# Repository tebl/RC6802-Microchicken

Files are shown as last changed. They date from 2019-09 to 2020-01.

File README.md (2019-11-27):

# RC6802 Microchicken

When starting out with retro computers, both fictional made homebrew or the commercial ones that were actually available for purchase in the 70s and 80s, there's one book in particular I've particularly enjoyed reading - that book is "22 micro-computer projects - to build, learn and learn" by Daniel Metzger (check out [ebay](http://ebay.com) or [abebooks.com](http://abebooks.com) for a copy). Written in 1985 on the tail-end of the homebrew computer-period, it gathers what I believe is the culmination of 10 years of teaching basic electronics, digital logic and computers to people without any prior knowledge for any of those things - perfect for me!

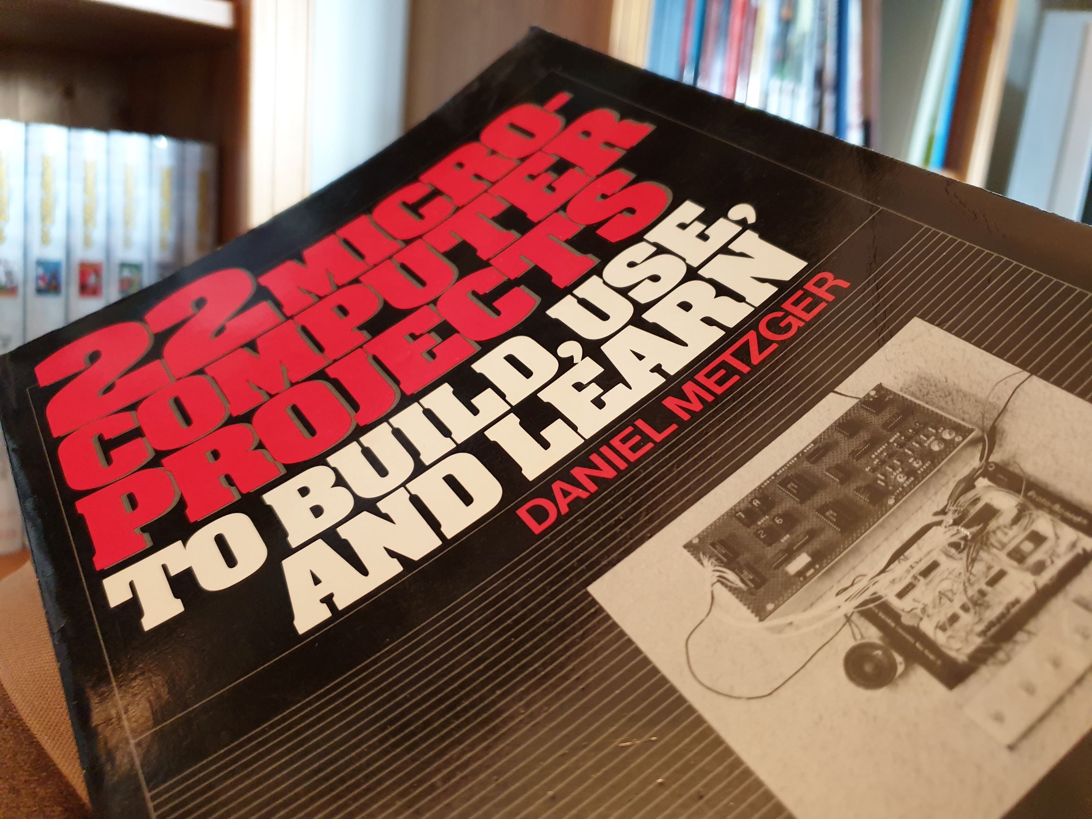
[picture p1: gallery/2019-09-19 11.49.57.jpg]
22 micro-computer projects - to build, learn and learn


The book builds upon each chapter by building a computer based on the 6802-processor from Motorola, a mysteriously similar processor to the now far more popular 6502. While it might be seen as an odd choice for a main processor these days, even the most advanced circuits are easily adapted to the 6502 as well. Nearly every other book I've got in my bookshelf never seem to describe much past the basics, usually circuits for storage (tape-based), single-step circuits as well as using a Video Display Generator are details left for other books to fill - this is the only book I've got that actually shows how to implement them in an easy and understandable way.

The final projects in the book result in the Microchicken-computer, which I've adapted and laid out in the form of the RC6802 Microchicken computer. I have no idea why it's called the *Microchicken*, other than that the book author obviously had a peculiar sense of humour that I can't help but agree with. My current build of the computer is shown below, I also made a short [YouTube](https://www.youtube.com/watch?v=bi4SIbvGzfI)-clip where I push some of its buttons - a whole bunch of times!

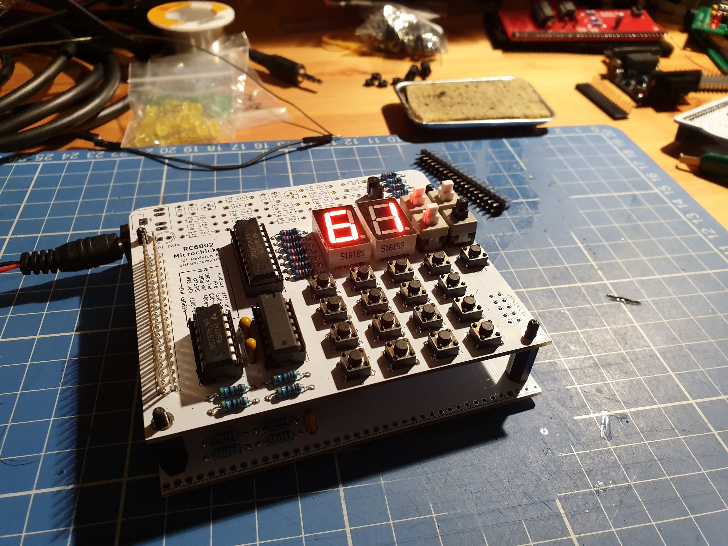
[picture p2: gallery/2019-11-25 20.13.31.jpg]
RC6802 Microchicken Computer


The monitor software for the RC6802 Microchicken, like the hardware design itself, is also included in the aforementioned book. I've transcribed in and slightly adapted the assembly code so that it can be assembled using modern tools, the one I've chosen to use is [SB-Assembler 3](https://www.sbprojects.net/sbasm/) as it seems to support all of the 8bit CPUs I've managed to force upon it. For a further description on the various functions of the monitor and the firmware in , see its specific [README](https://github.com/tebl/RC6802-Microchicken/tree/master/software/firmware)-file as well. 

## Modules
As with most of my computer builds the computer have been split into two required main boards to stay under the magic 5$ cost limits over at [PCBWay](https://www.pcbway.com/setinvite.aspx?inviteid=88707) for each, a CPU board as well as a UI board sandwiched on top. There may be additional modules found among the project files, but the ones I've added here are the ones that have been considered ready.

| Module | RC6802 Microchicken | Expanded system | Order |
| --- | --- | --- | ----- |
| [CPU](https://github.com/tebl/RC6802-Microchicken/tree/master/RC6802%20CPU) | required | required | [PCBWay](https://www.pcbway.com/project/shareproject/RC6802_Microchicken__CPU_module_revision_B_.html?inviteid=88707) |
| [User Interface](https://github.com/tebl/RC6802-Microchicken/tree/master/RC6802%20UI) | required | required | [PCBWay](https://www.pcbway.com/project/shareproject/RC6802_Microchicken__UI_module_revision_B_.html?inviteid=88707) |
| [Backplane](https://github.com/tebl/RC6502-Apple-1-Replica/tree/master/RC6502%20Backplane) | | required | [PCBWay](https://www.pcbway.com/project/shareproject/RC6502_Apple_1_Replica__Backplane_module_revision_A_.html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) |
| [Prototyping module](https://github.com/tebl/RC6502-Apple-1-Replica/tree/master/RC6502%20Prototyping) | | optional | [PCBWay](https://www.pcbway.com/project/shareproject/RC6502_Apple_1_Replica__Module_prototyping_board_.html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) |

As modules are constantly being worked on, I've also added an order link to the modules so that you can always get the last version I know works. Click the module name for more information about that specific module, including schematic and the list of parts you'd need to build it (BOM).

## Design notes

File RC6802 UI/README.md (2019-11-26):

# RC6802 Microchicken

One of my most enjoyable reads the past year has been "22 micro-computer projects - to build, learn and learn" by Daniel L. Metzger, the Microchicken-computer is described in detail within it and so I sought to build one myself. The computer has been designed as a set of smaller modules, for an overall description a listing of the available modules - see the main project [README](https://github.com/tebl/RC6802-Microchicken)!

## User Interface
The User Interface module has been designed to stack on top of the CPU-module, doing it this way the overall project stays within manageable PCB-costs and should be buildable for anyone with a reasonable set of tools available. An assembled version of the CPU-module by itself as well as a version stacked underneath the User Interface module can be seen below.

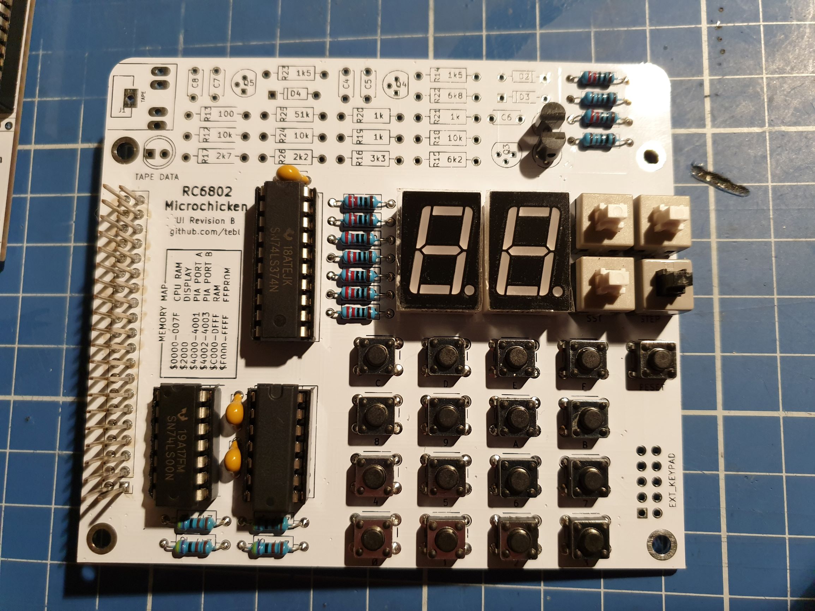
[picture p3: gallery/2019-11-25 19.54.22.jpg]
Assembled User Interface

Stacked boards

The User Interface has two 7-segment displays as well as a 16-key keypad, all of the keypad pins have also been brought out to a separate connector so that an external keypad can also be used instead of the onboard-one (easier when using the computer with a backplane and additional expansions). It has an implementation of the described SST-circuit for the 6802 processor as well as being able to latch the IRQ-line permanently low, this is used by the monitor as a software-based alternative for stepping through code.

Additionally a circuit for loading and saving data using audio tapes is also available as an option, I only had room to add the one audio connector so I used a single 3.5mm connector instead. I used the same pinouts as on the ZX Spectrum +3, so the same tape cables can be used with the RC6802 and you should be able to find a new set of these cables via ebay as they are still being made today.

# Schematic
The supplied KiCad files should be sufficient as both a schematic and as a starting point for ordering PCBs (basically you could just zip the contents of the export folder and upload that on a fabrication site), the schematic is also available in [PDF-format](https://github.com/tebl/RC6802-Microchicken/raw/master/RC6802%20UI/export/RC6802%20UI.pdf) so that you print it out and hang it on your office wall, excellent conversation starter at any technology-oriented business worth working at (or so I keep telling myself)!

If you require more assistance, there is also a separate [Troubleshooting](https://github.com/tebl/RC6802-Microchicken/blob/master/Troubleshooting.md) guide as part of the supplied documentation. Also make sure to have a read through the [Manual](https://github.com/tebl/RC6802-Microchicken/blob/master/Manual.md) to see if it's a *feature* instead! Some of these documents may not actually exist at the time of clicking on them.

# BOM
This is the part list as it stands now, most should be easy to get a hold of from your local electronic component shop though you might have to consider other sources depending on the quality of your local vendor. Values in parenthesis are optional components that might not be needed (mainly the tape interface and the SST-circuit).

Some vendors will have the same ICs in different form factors, the ones you want will often be specified as being in the form of a DIP/PDIP package - usually you'll want sockets for each of them as well. For the pin headers, you probably won't find the exact pin count so just buy the 40 pin versions and snip off the parts you don't need.

| Reference | Item | Count |
| --- | --- | ----- |
| PCB | Fabricate yourself using Gerber files | 1 |
| AFF1-AFF2 | 0.56" 7-segment displays (C.A.) | 2 |
| C1-C3 | 100nF ceramic capacitor | 3 |
| C4,C6 | 50nF ceramic capacitor | (2)|
| C5 | 68nF ceramic capacitor | (1)|
| C8 | 100nF ceramic capacitor | (1)|
| D1 | 5mm LED | (1)|
| D2-D4 | 1N4148 small signal diode | (3)|
| J1 Audio | 3.5mm 5pin green audio socket (PJ307) | (1)|
| J2 | 2x20 female header pins * | 1 |
| J3 | 2x5 right-angle header pins | (1)|
| Q1-Q2 | 2N3906 TO-92 transistor | 2 |
| Q3-Q5 | 2N3904 TO-92 transistor | (3)|
| R13 | 100 ohm resistor | (1)|
| R27,R29 | 220 ohm resistor | 2 |
| R28,R30 | 1k (1000) ohm resistor | 2 |
| R19-R21 | 1k ohm resistor | (3)|
| R14,R23 | 1k5 (1500) ohm resistor | (2)|
| R1-R4 | 4k7 (4700) ohm resistor | 4 |
| R26 | 2k2 (2200) ohm resistor | (1)|
| R17 | 2k7 (2700) ohm resistor | (1)|
| R22 | 6k8 (6800) ohm resistor | (1)|
| R12,R18,R24 | 10k ohm resistor | (3)|
| R25 | 51k ohm resistor | (1)|
| SW1,SW3-SW18 | Momentary push button | 17 |
| SW2,SW19,SW21 | 6pin 8.5mm x 8.5mm latching switch | (3)|
| SW20 | 6pin 8.5mm x 8.5mm non-latching switch| (1)|
| U1 | 74LS374 (DIP-20) | 1 |
| U2 | 74LS00 (DIP-14) | 1 |
| U3 | 74LS73 (DIP-14) | (1)|
| | M3 nylon hex standoffs ** | 4 |
| | M3 nylon screws ** | 4 |
| | M3 nylon nuts ** | 4 |

*) An ordinary set of 2x20 female header pins can be installed on the reverse-side, but since the connector has quite a few signals that could be used for your own projects later I recommend getting ones with the longer pins - these are most oftenly found listed as a stacking Raspberry Pi header. Slot onto CPU-module using M3 standoffs before soldering to get the spacing correct.

**) The length of the nylon standoffs depend on the female header pins used, extra length (M3x12mm) or the ordinary non-stacking variant (M3x10mm). Better yet, get one of those $4 M3 Nylon Stand-off sets from China - that way you're all set for a few projects down the road as well.

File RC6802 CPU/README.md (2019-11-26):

# RC6802 Microchicken

One of my most enjoyable reads the past year has been "22 micro-computer projects - to build, learn and learn" by Daniel L. Metzger, the Microchicken-computer is described in detail within it and so I sought to build one myself. The computer has been designed as a set of smaller modules, for an overall description a listing of the available modules - see the main project [README](https://github.com/tebl/RC6802-Microchicken)!

## CPU
The CPU module has been designed to stack with the User Interface-module, doing it this way the overall project stays within manageable PCB-costs and should be buildable for anyone with a reasonable set of tools available. An assembled version of the CPU-module by itself as well as a version stacked underneath the User Interface module can be seen below.

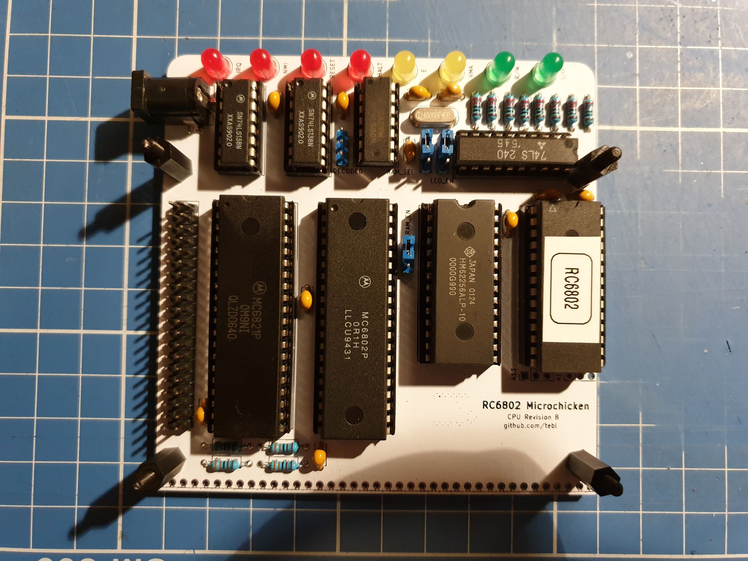
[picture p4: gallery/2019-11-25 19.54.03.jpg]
Assembled CPU Board

Stacked boards

The CPU board is actually a complete SBC (Single Board Computer) by itself, meaning that it can be used either standalone though you'd probably need to add some sort of additional hardware in order to see anything actually running. I hope to build more modules that can be used with it other than the standard User Interface. 

Some of the ICs however have been changed out with components that should be easier to source for a lot less money. For those that find themselves wondering why there are ICs with more capacity (RAM/ROM) than is actually available to the system, it's simply because they were cheaper than the smaller capacity variants and I didn't want to lay claim to more of the address space than what the original computer calls for (8K for each).

## Jumpers
| Reference | Position | Description |
| --- | --- | --- |
| RAM_EN | 1-2 * | Enable on-chip 128 bytes of memory on 6802 CPU |
| | 2-3 | Disable on-chip memory or jumper if using 6808 CPU |
| RAM_SEL | 1-2 * | 8K of static RAM on addresses $C000-$DFFF |
| | 2-3 | 8k of static RAM on addresses $0000-$1FFF |
| LED_EN | 1-2 * | Enable status LEDs |
| | 2-3 | Disable status LEDs |
| A14, A13  | 1-2 ** | EEPROM 8K window selection (sets line HIGH) |
| | 2-3 ** | EEPROM 8K window selection (sets line LOW) |

*) Marks the default jumpered positions for a standalone RC6802 system with 6802 CPU installed.
**) A14 and A13 must be jumpered when using 28C256 EEPROM, leave unjumpered when using the lower capacity 28C64 EEPROM instead.

# Schematic
The supplied KiCad files should be sufficient as both a schematic and as a starting point for ordering PCBs (basically you could just zip the contents of the export folder and upload that on a fabrication site), the schematic is also available in [PDF-format](https://github.com/tebl/RC6802-Microchicken/raw/master/RC6802%20CPU/export/RC6802%20CPU.pdf) so that you print it out and hang it on your office wall, excellent conversation starter at any technology-oriented business worth working at (or so I keep telling myself)!

If you require more assistance, there is also a separate [Troubleshooting](https://github.com/tebl/RC6802-Microchicken/blob/master/Troubleshooting.md) guide as part of the supplied documentation. Also make sure to have a read through the [Manual](https://github.com/tebl/RC6802-Microchicken/blob/master/Manual.md) to see if it's a *feature* instead! Some of these documents may not actually exist at the time of clicking on them.

# BOM
This is the part list as it stands now, most should be easy to get a hold of from your local electronic component shop though you might have to consider other sources depending on the quality of your local vendor. Values in parenthesis are optional components that might not be needed (status LEDs and when using 28C256 EEPROMs).

Some vendors will have the same ICs in different form factors, the ones you want will often be specified as being in the form of a DIP/PDIP package - usually you'll want sockets for each of them as well. For the pin headers, you probably won't find the exact pin count so just buy the 40 pin versions and snip off the parts you don't need.

| Reference | Item | Count |
| --- | --- | ----- |
| PCB | Fabricate yourself using Gerber files | 1 |
| C1-C8,C10 | 100nF ceramic capacitor | 9 |
| C9,C11 | 22pF ceramic capacitor | 2 |
| D1-D8 | 5mm LED (assorted colours) | (8)|
| J1 | 39p right angle pin header | (1)|
| J2 | 2x20 pin straight header | 1 |
| J3 | 2.1mm x 5.5mm barrel plug | 1 |
| J4,JP7-JP8 | Single row, 3 pin straight  header | (3)|
| JP2,JP3 | Single row, 3 pin straight  header | 2 |
| R1-R4 | 3k3 (3300) ohm resistor | 4 |
| R5-R12 | 220 ohm resistor | (8)|
| U1 | MC6802 CPU (DIP-40) * | 1 |
| U2 | 62256 Static RAM (DIP-28) | 1 |
| U3 | 28C64/28C256 EEPROM (DIP-28) | 1 |
| U4 | 74LS00 (DIP-14) | 1 |
| U6 | MC6821 PIA (DIP-40) | 1 |
| U7 | 74LS138 (DIP-16) | 1 |
| U8 | 74LS240 (DIP-20) | (1)|
| Y1 | 4Mhz crystal (HC-49) | 1 |
| | Jumpers for settings (CAP headers) | 5 |

*) You can also use an MC6808 processor, read jumpers descriptions on how to do this. The 6808 lacks the on-chip memory found on the 6802, so it needs to be jumpered as disabled with static memory moved into the lower addresses instead.

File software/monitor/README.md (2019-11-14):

# Firmware
The monitor software for the RC6802 Microchicken, like the hardware design itself - it is taken from the book "22 Micro-computer projects: To build, use, and learn" by the late Daniel Metzger. The assembly code listed in the book has been transcribed by me, then adapted slightly so that the code assembles as expected when using [SB-Assembler 3](https://www.sbprojects.net/sbasm/).

SB-Assembler 3 is available for all major platforms, so apart from my simple little batch file to run it there shouldn't be any other steps necessary other than adding it to the system PATH environment variable. If you do not wish to alter the code, then the Intel HEX file should be suitable for flashing onto a 28C64 EEPROM - an additional file, monitor.list makes reading the code easier when debugging the software. The batch file is just there because I'm too lazy to type the command, so I'll just click it instead. Essentially what it does is this:
```
sbasm.py monitor.asm
```

## MICROCHICKEN 6802 MONITOR
Microchicken 6802 Monitor is copyright 1984 by the late Daniel L. Metzger, and as already mentioned I've reproduced the listing from his book in the hope that it again ends up teaching someone, something, someday.

The Microchicken monitor is a simple operating system for the 6802 microcomputer, it permits commands and data to be input to the computer via the hex keyboard (either directly on the UI module or via an external keypad). Data is displayed on two 7-segment displays found on the UI-module, the monitor contains a lookup table used when translating from binary hex digits into the corresponding display segments.

Pressing the *RESET*-button causes the program to start scanning the keyboard for the function (*FCN*) to be performed, any subsequent key entries access new functions according to the key pressed. Read the description for each function for a description of what to do from there, hit *RESET* again to exit out of the function.

**NB!** The *RESET* button is resetting the CPU, so just press and release *RESET* - then press a digit to enter the function as described below.

### (FCN-0) Set address
Enter address using keypad, 4 key inputs - address entered will be shown on the display. Both bytes, HI and LO will be flashed briefly on the displays followed by a blanking period when all digits of the address has been entered.

### (FCN-1) Display address
Displays data, 2 digits, of the currently set address on the first press. The address will automatically be incremented on subsequented presses of the *1*-key, allowing you to step through and verify a program you've keyed in before running it.

### (FCN-2) Set data
Displays data stored in currently set address on first press. New data (2 digits) is then entered via the hex keypad, the address is automatically incremented on subsequent pairs of keystrokes. Use *RESET* to stop entering data.

### (FCN-3) Display data
Displays data stored in currently set address on the first press. Subsequent presses of the *3* decrements the currently set address and displays the data stored there instead - this allows you to verify entered using FCN-2 in reverse order. Alternatively you could set the address to the start of your program using FCN-0 and then stepping through the data using FCN-1.

### (FCN-4) Run program
Executes the program starting at the currently set address.

### (FCN-5) Run from start
Computer will jump to address $0001, the then it will start executing instructions from there.

### (FCN-6) Burn EPROM
The book the that describes the Microchicken computer also include instructions for building a simple EPROM burner for 2716 EPROMs. This part of the hardware may be added in a future revision, or stripped out entirely because I wanted the function number for something else.

The function expects the RAM address of where the data to be written starts, this is as commonly expected stored with HI address $7A and LO at $7B. Data end address will likewise have to be put in addresses $7C/$7E. The address of where to start within the EPROM must be set up in addresses $7E/$7F. Takes 50ms per byte to run, displays ROM low address while programming followed by RAM end address when done - displays bad EPROM adress if data verification fails.

### (FCN-7) Dump EPROM
Dump contents of EPROM connected to the EPROM-burner part of the Microchicken, if you have this expansion for it (and you probably designed and built it yourself). See FCN-6 for more information.

RAM start address must be stored at $7A (HI)/$7B (LO), RAM end address at $7C/$7D. ROM start address at $7E/$7F.

### (FCN-8) Save RAM to TAPE
Saves RAM to tape using the tape interface included on the UI-module, this version of the hardware uses a single 3.5mm jack for both the EAR (data from tape to computer) and MIC (data from computer to tape) and uses the same cable used with the ZX Spectrum +3 as those are still being produced.

The tape interface will output one bit at a time, generating a 18 cycles with 3600Hz tone for a 0 or 9 cycles for a 1 done in an 8ms field. Note that this is dependent on the CPU speed and these values correspond to a default system clock running at around 1Mhz.   

Store starting address in RAM address $7A (HI) and $7B (LO), ending address at $7C/$7D. Takes 64ms per byte; 16 seconds per page. RAM end address will be displayed when done. Note that when loading data from tape, you'll need to know the length of the program in bytes as a the code does not write something akin to a program header to the tape.

### (FCN-9) Load data from TAPE
See FCN-8 for more details on the hardware-side of things. Store starting address in RAM address $7A (HI) and $7B (LO), ending address at $7C/$7D. The last address will be shown on the display when the program has read the specified number of bytes.

### (FCN-A) Display accumulator A
Displays the contents of accumulator A. Used after single-stepping code using the HW SST circuit.

### (FCN-B) Display accumulator B
Displays the contents of accumulator B. Used after single-stepping code using the HW SST circuit.

### (FCN-C) Display condition-code register
Displays the contents of the condition-code register, used after single-stepping code with the HW SST circuit. The register display bits are setup as following (see 6800 documentation for further details):

| bit | 7 | 6 | 5 | 4 | 3 | 2 | 1 | 0 |
| --- | - | - | --- | --- | --- | --- | --- | --- |
| | - | - | **H**alf-carry | **I**nterrupt mask | **N**egative | **Z**ero | o**V**erflow | **C**arry |

### (FCN-D) Display index register (X)
Displays the contents of the 16bit index register (X), used after single-stepping code with the HW SST circuit. HI and LO bytes will be flashed on displays, with a short pause before repeating.

### (FCN-E) Display program counter
Displays the contents of the 16bit program counter (PC), used after single-stepping code with the HW SST circuit this will show the address of the next instruction. HI and LO bytes will be flashed on displays, with a short pause before repeating.

### (FCN-F) Execute a single instruction
This function will execute a single instruction at the currently set address, performing the following steps:
1) Save the byte preceeding the user instruction, inserting a clear interrupt in its place.
2) Jumps to the "CLI" instruction. One user instruction will execute before IRQ is recognized, the IRQ handler will save all machine registers on stack and then go to *RETURN*.
3) Pull machine registers off stack, save contents in RAM buffers.
4) Replace inserted *CLI* instruction with the one overwritten in step 1.
5) Update program counter (PC) to point to the current address (ready for next step).

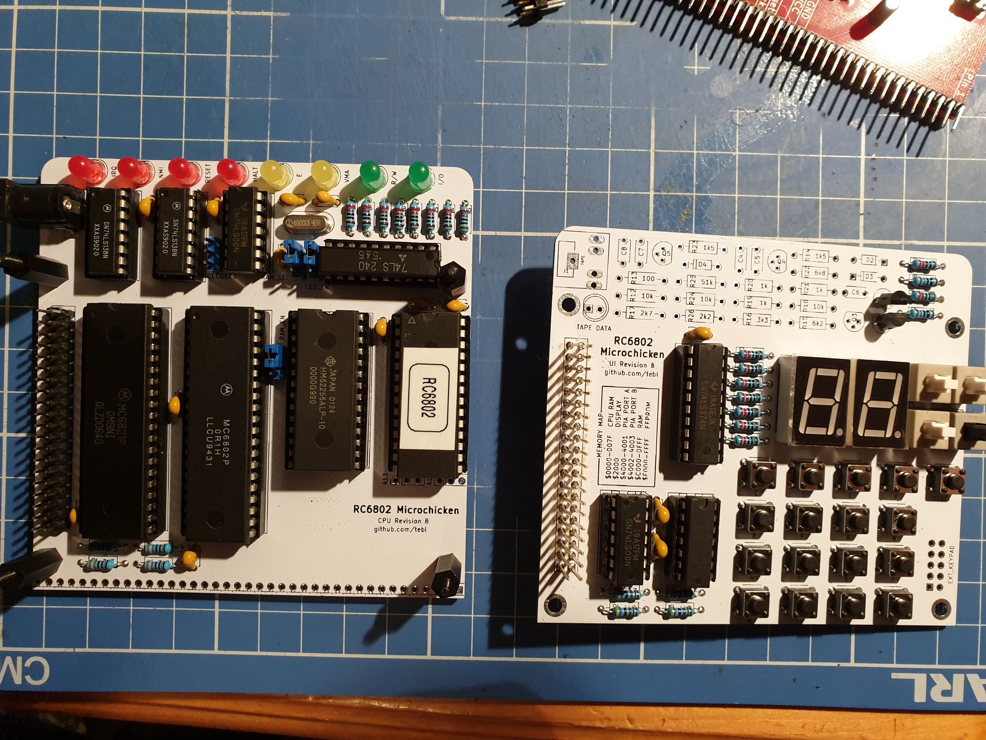
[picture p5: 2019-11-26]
gallery/2019-11-25 19.53.55.jpg

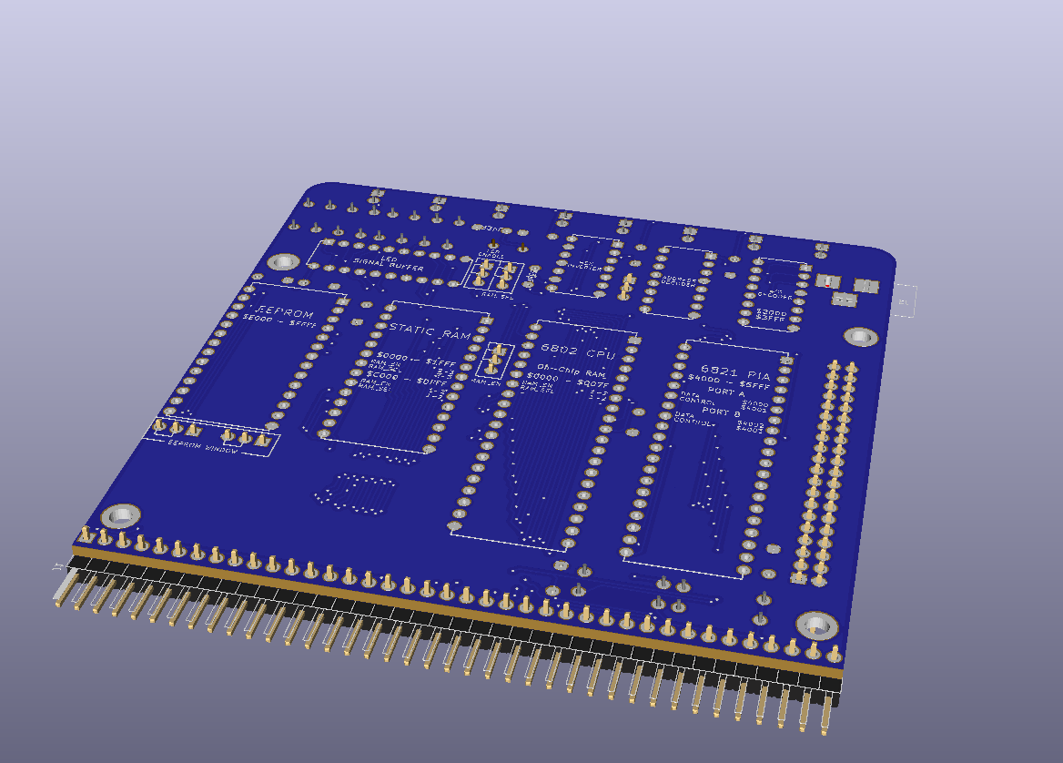
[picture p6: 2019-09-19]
RC6802 CPU/gallery/RC6802 CPU #2.png

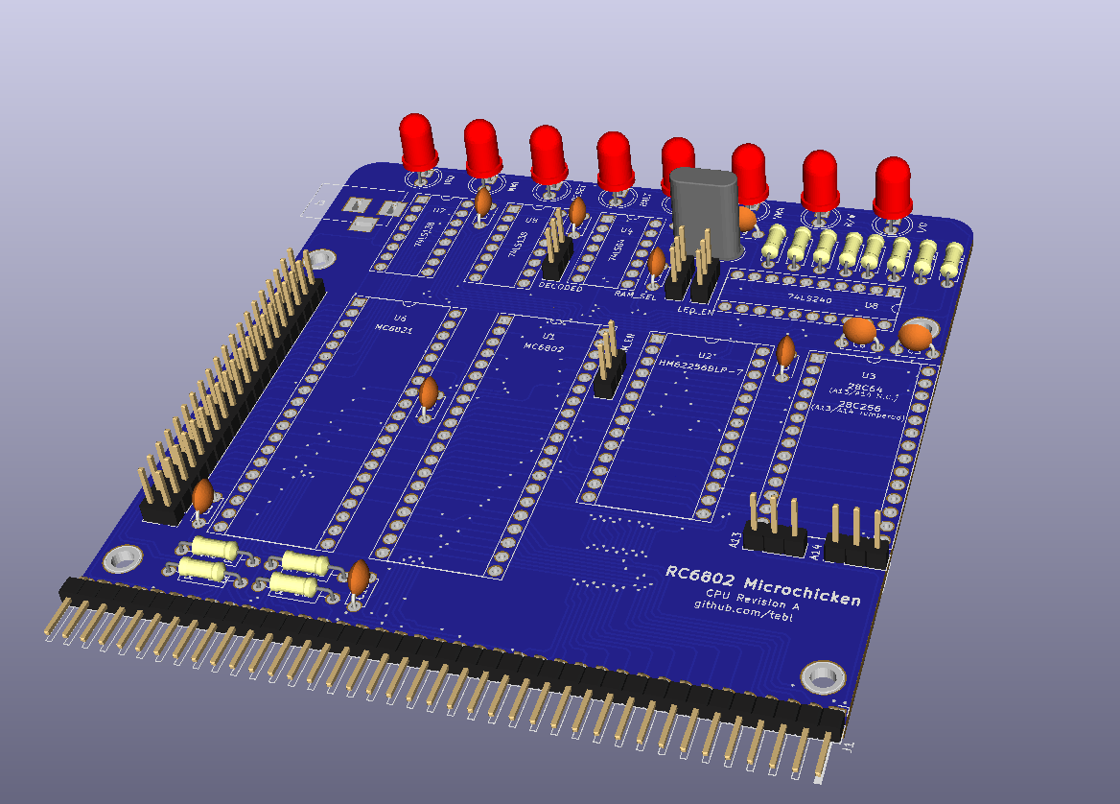
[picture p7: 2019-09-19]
RC6802 CPU/gallery/RC6802 CPU #1.png

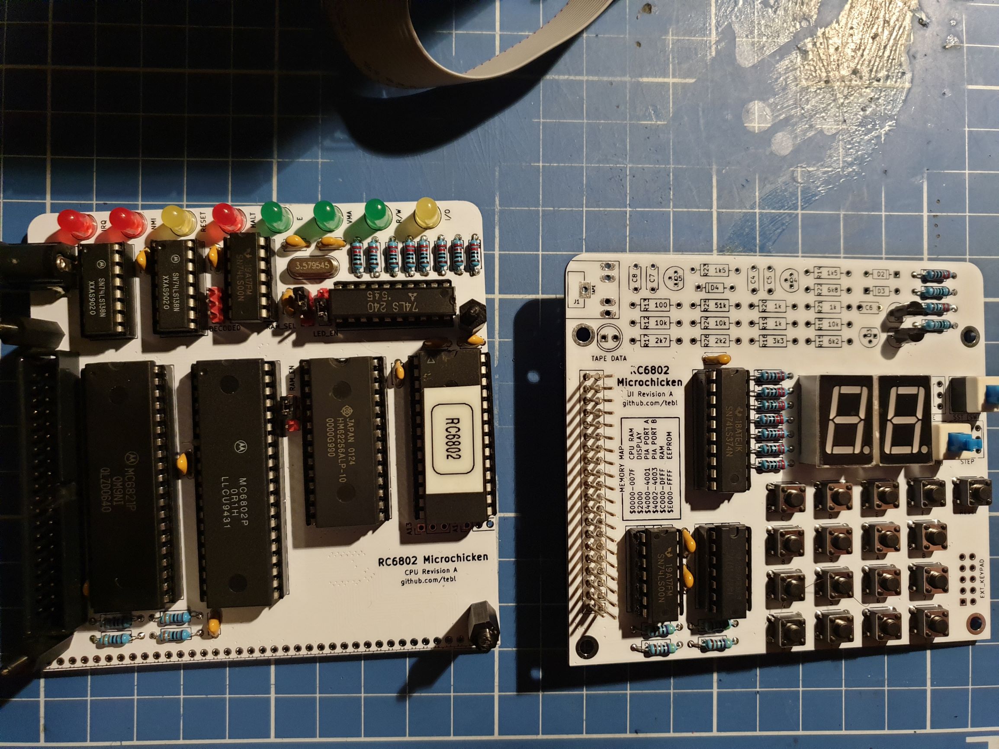
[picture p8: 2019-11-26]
gallery/2019-11-19 22.20.52.jpg

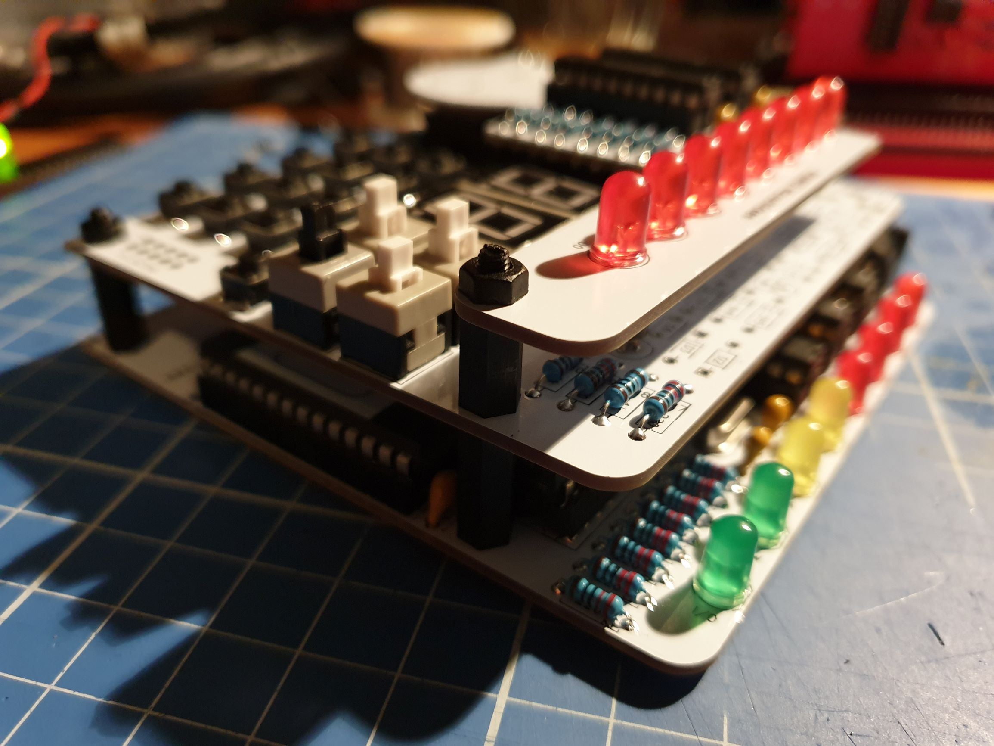
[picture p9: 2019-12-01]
gallery/2019-11-27 20.25.18.jpg

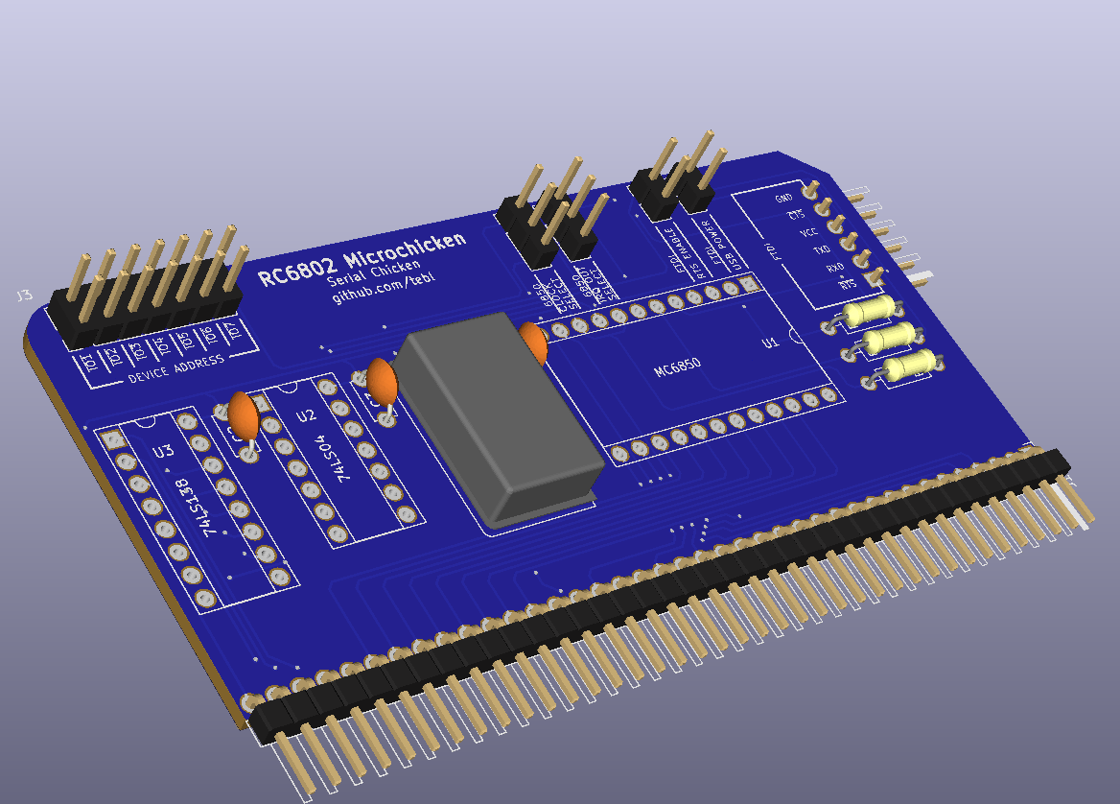
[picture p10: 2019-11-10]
RC6802 Serial Chicken/gallery/RC6802 Serial Chicken #1.png

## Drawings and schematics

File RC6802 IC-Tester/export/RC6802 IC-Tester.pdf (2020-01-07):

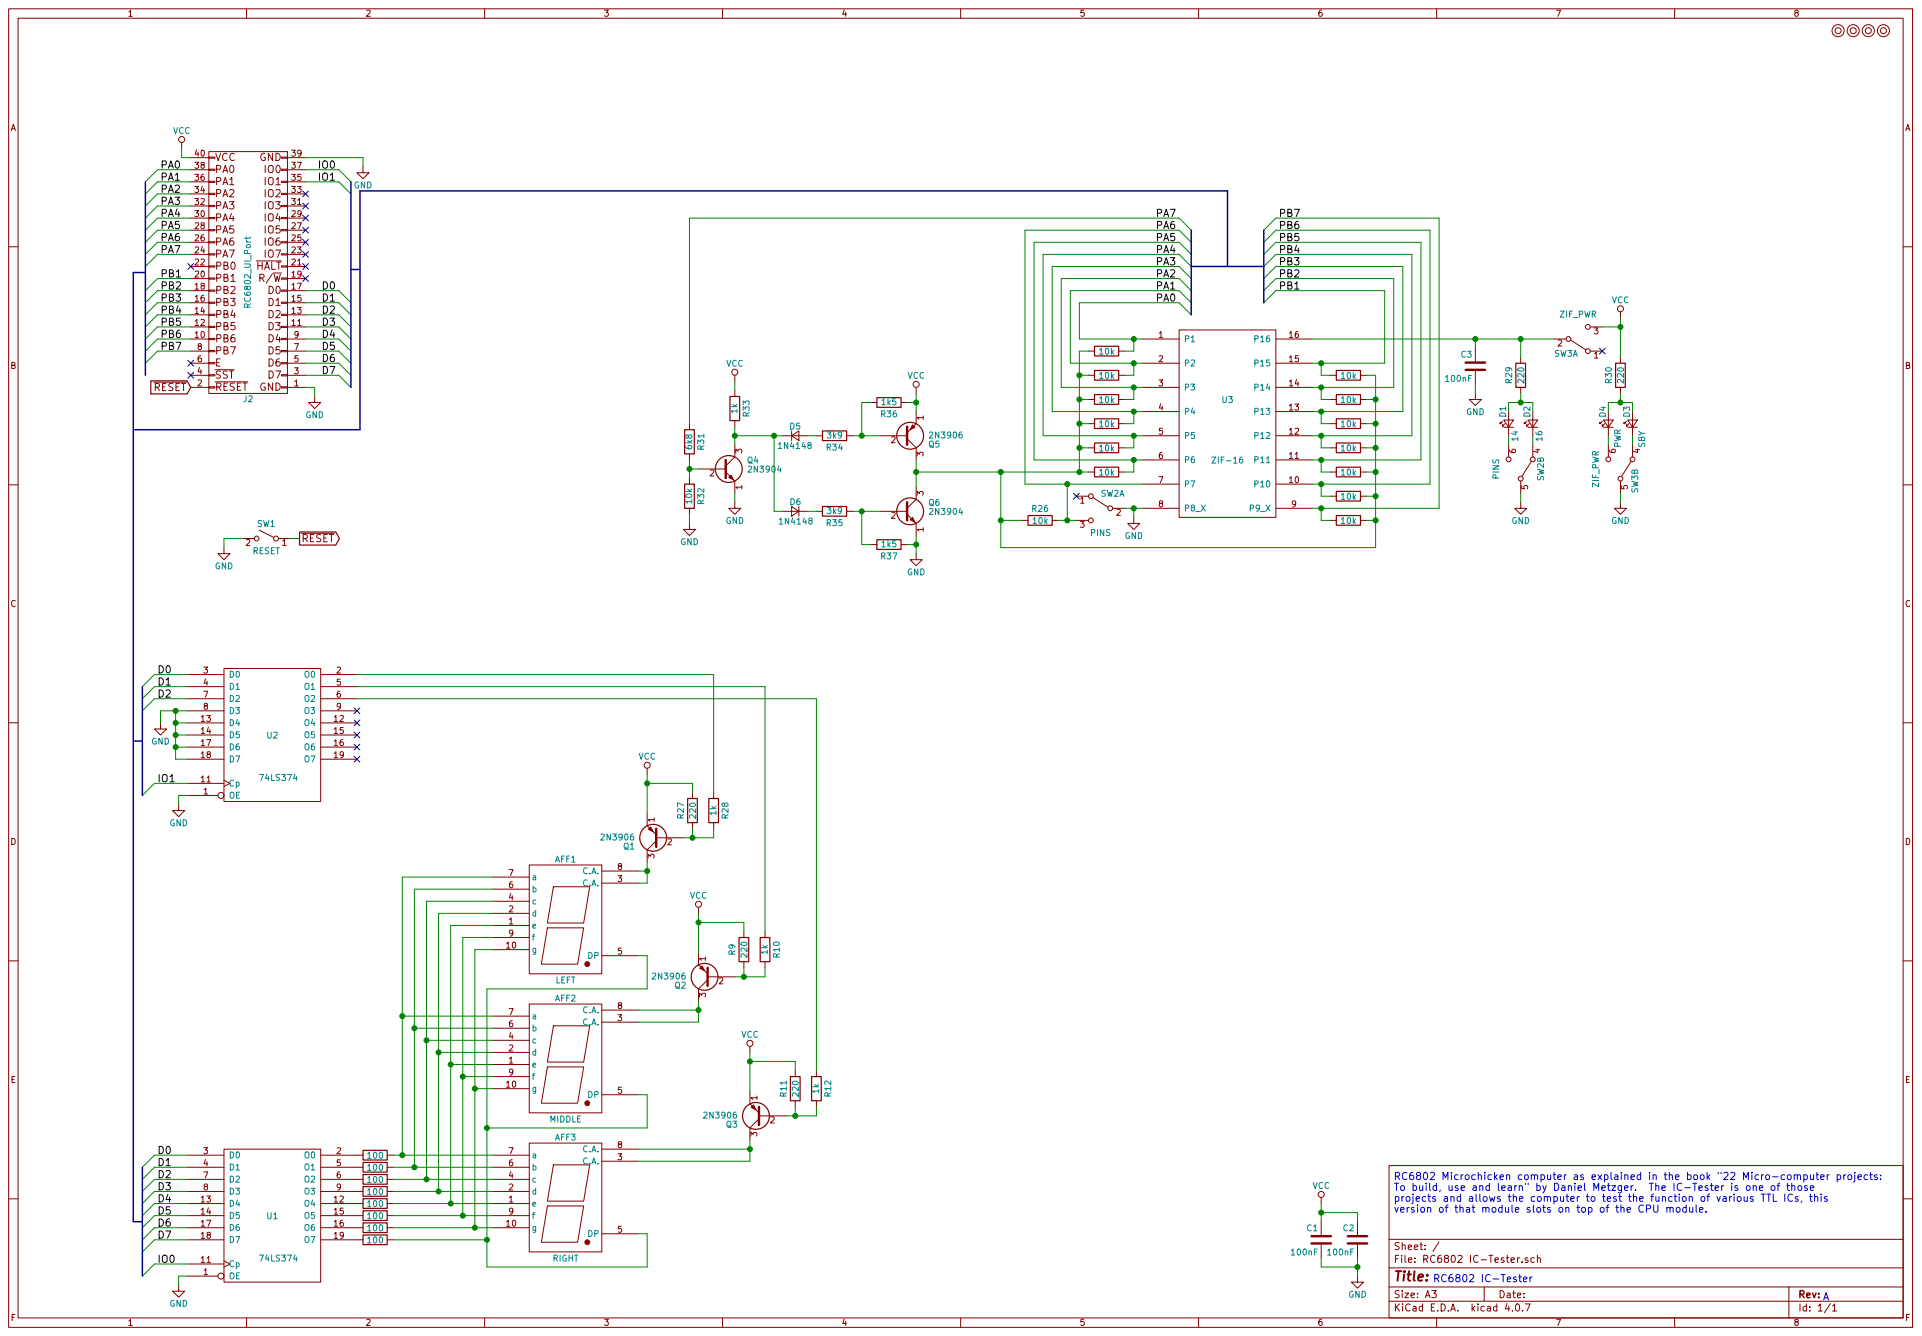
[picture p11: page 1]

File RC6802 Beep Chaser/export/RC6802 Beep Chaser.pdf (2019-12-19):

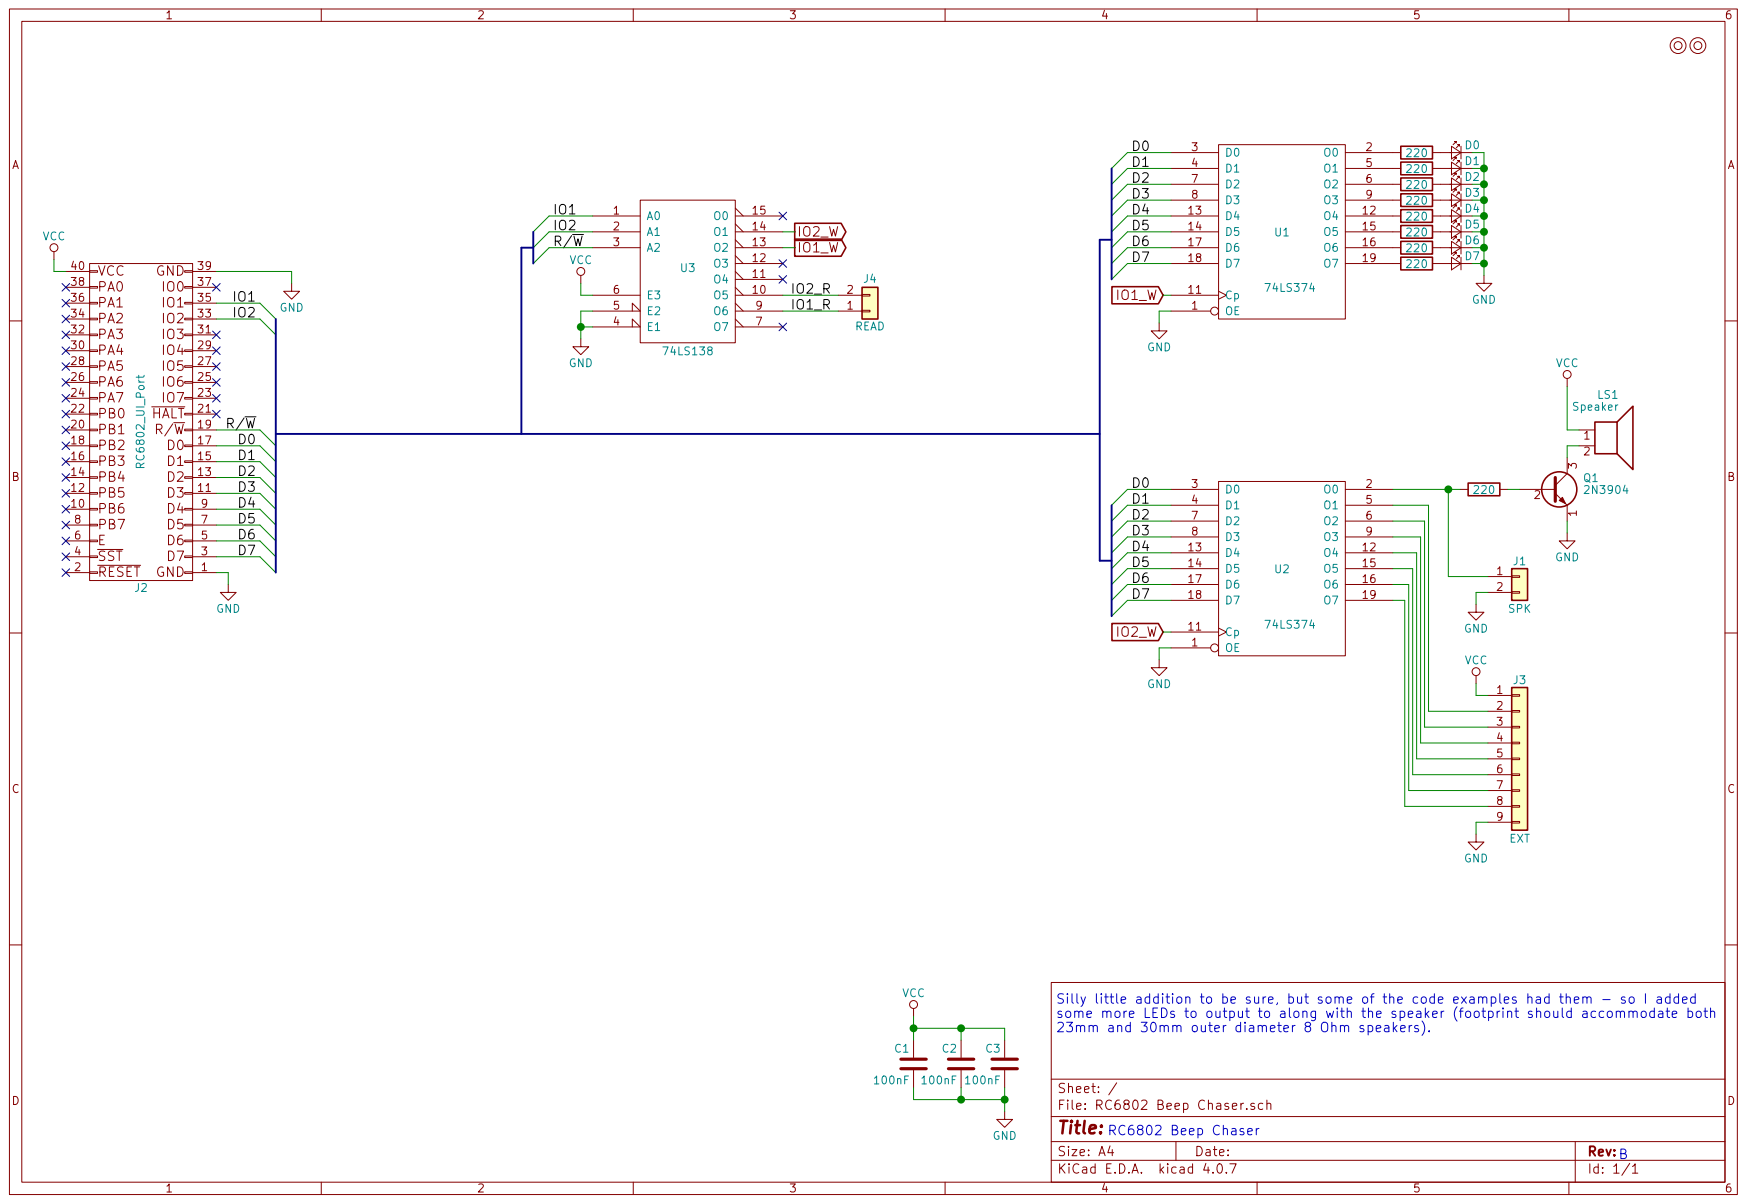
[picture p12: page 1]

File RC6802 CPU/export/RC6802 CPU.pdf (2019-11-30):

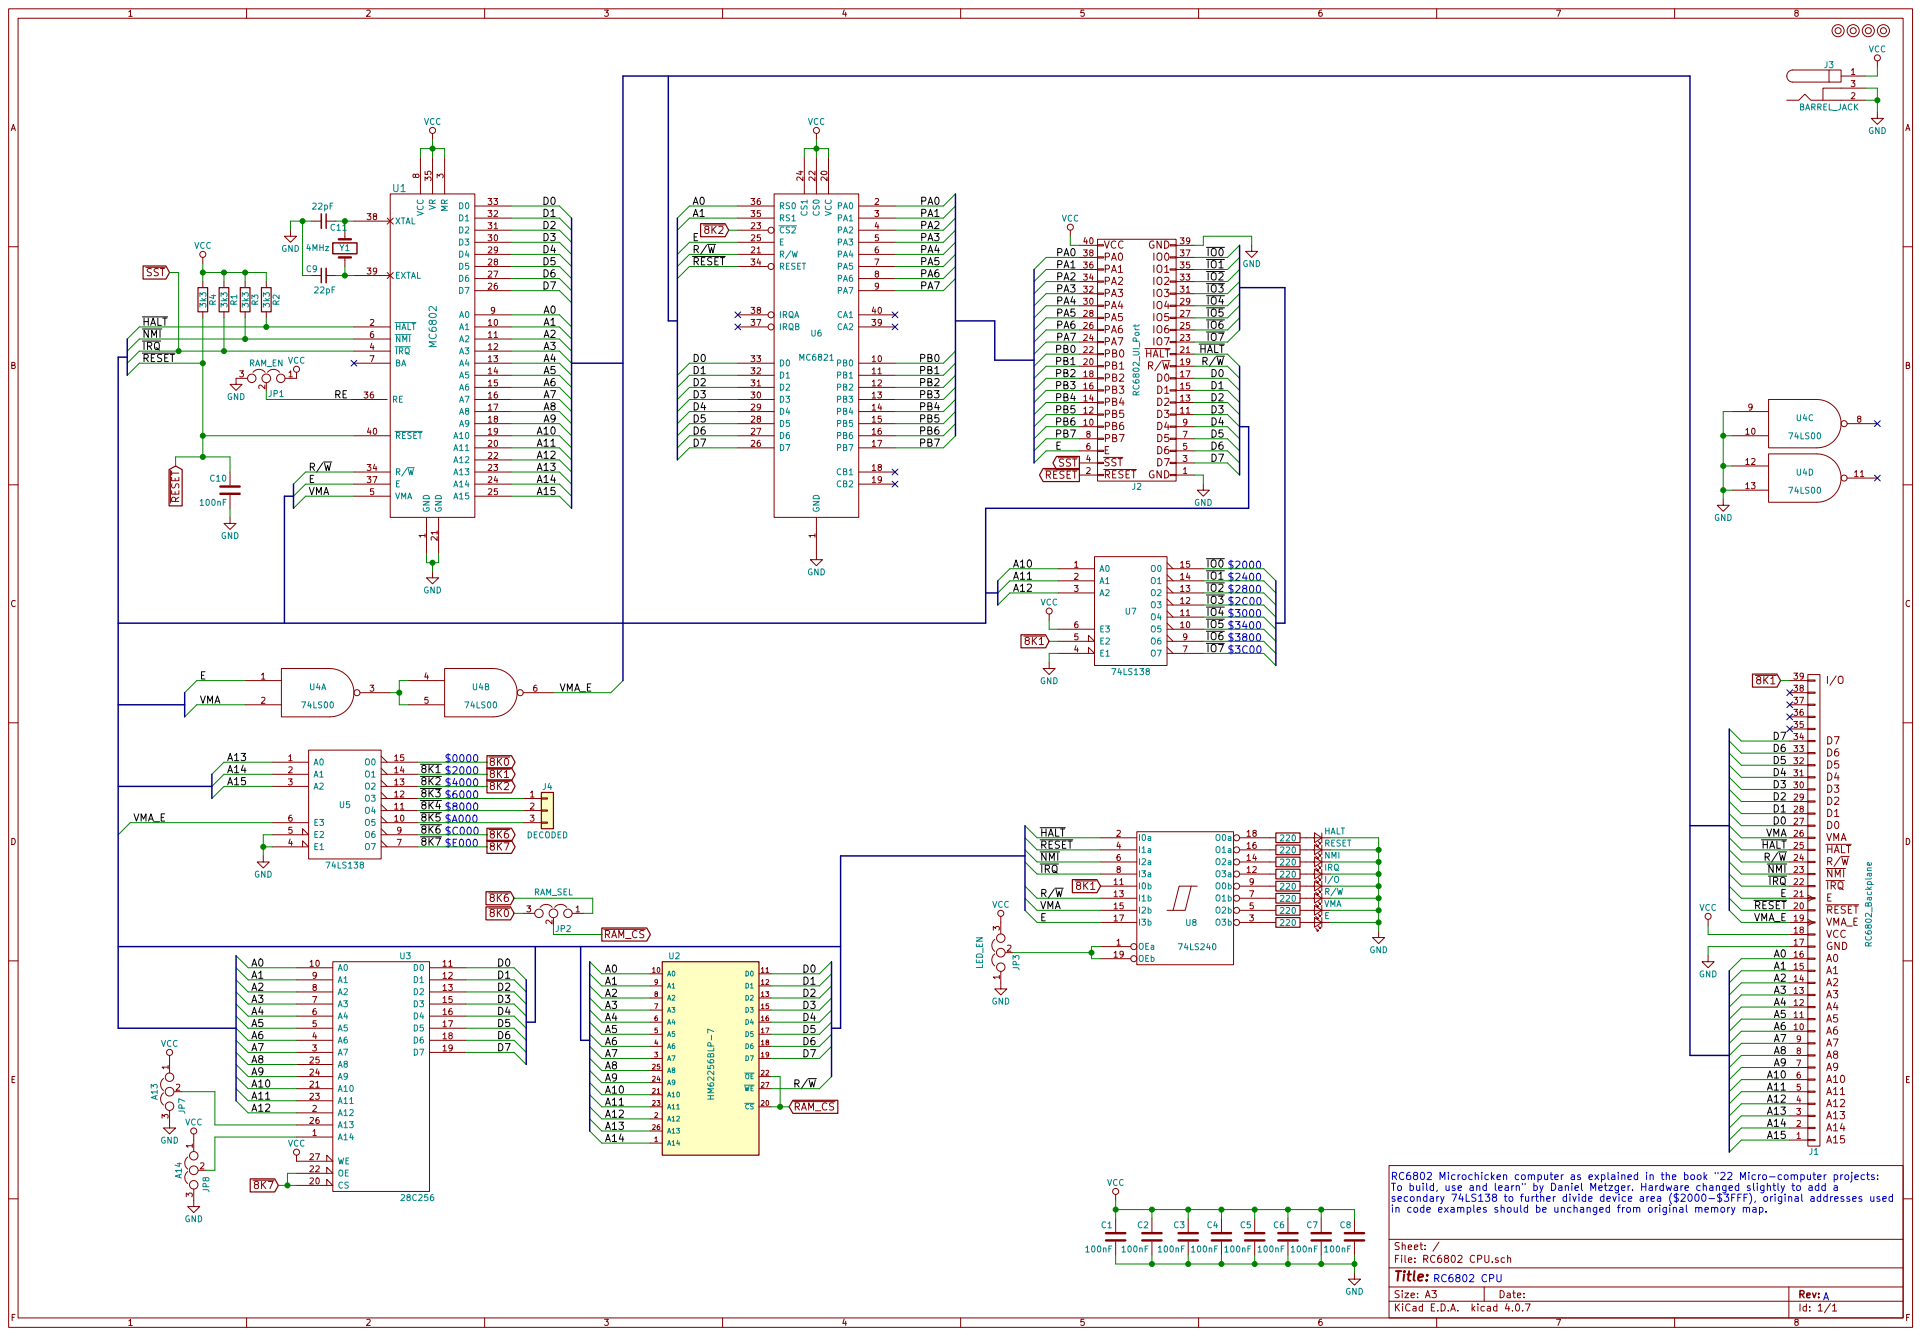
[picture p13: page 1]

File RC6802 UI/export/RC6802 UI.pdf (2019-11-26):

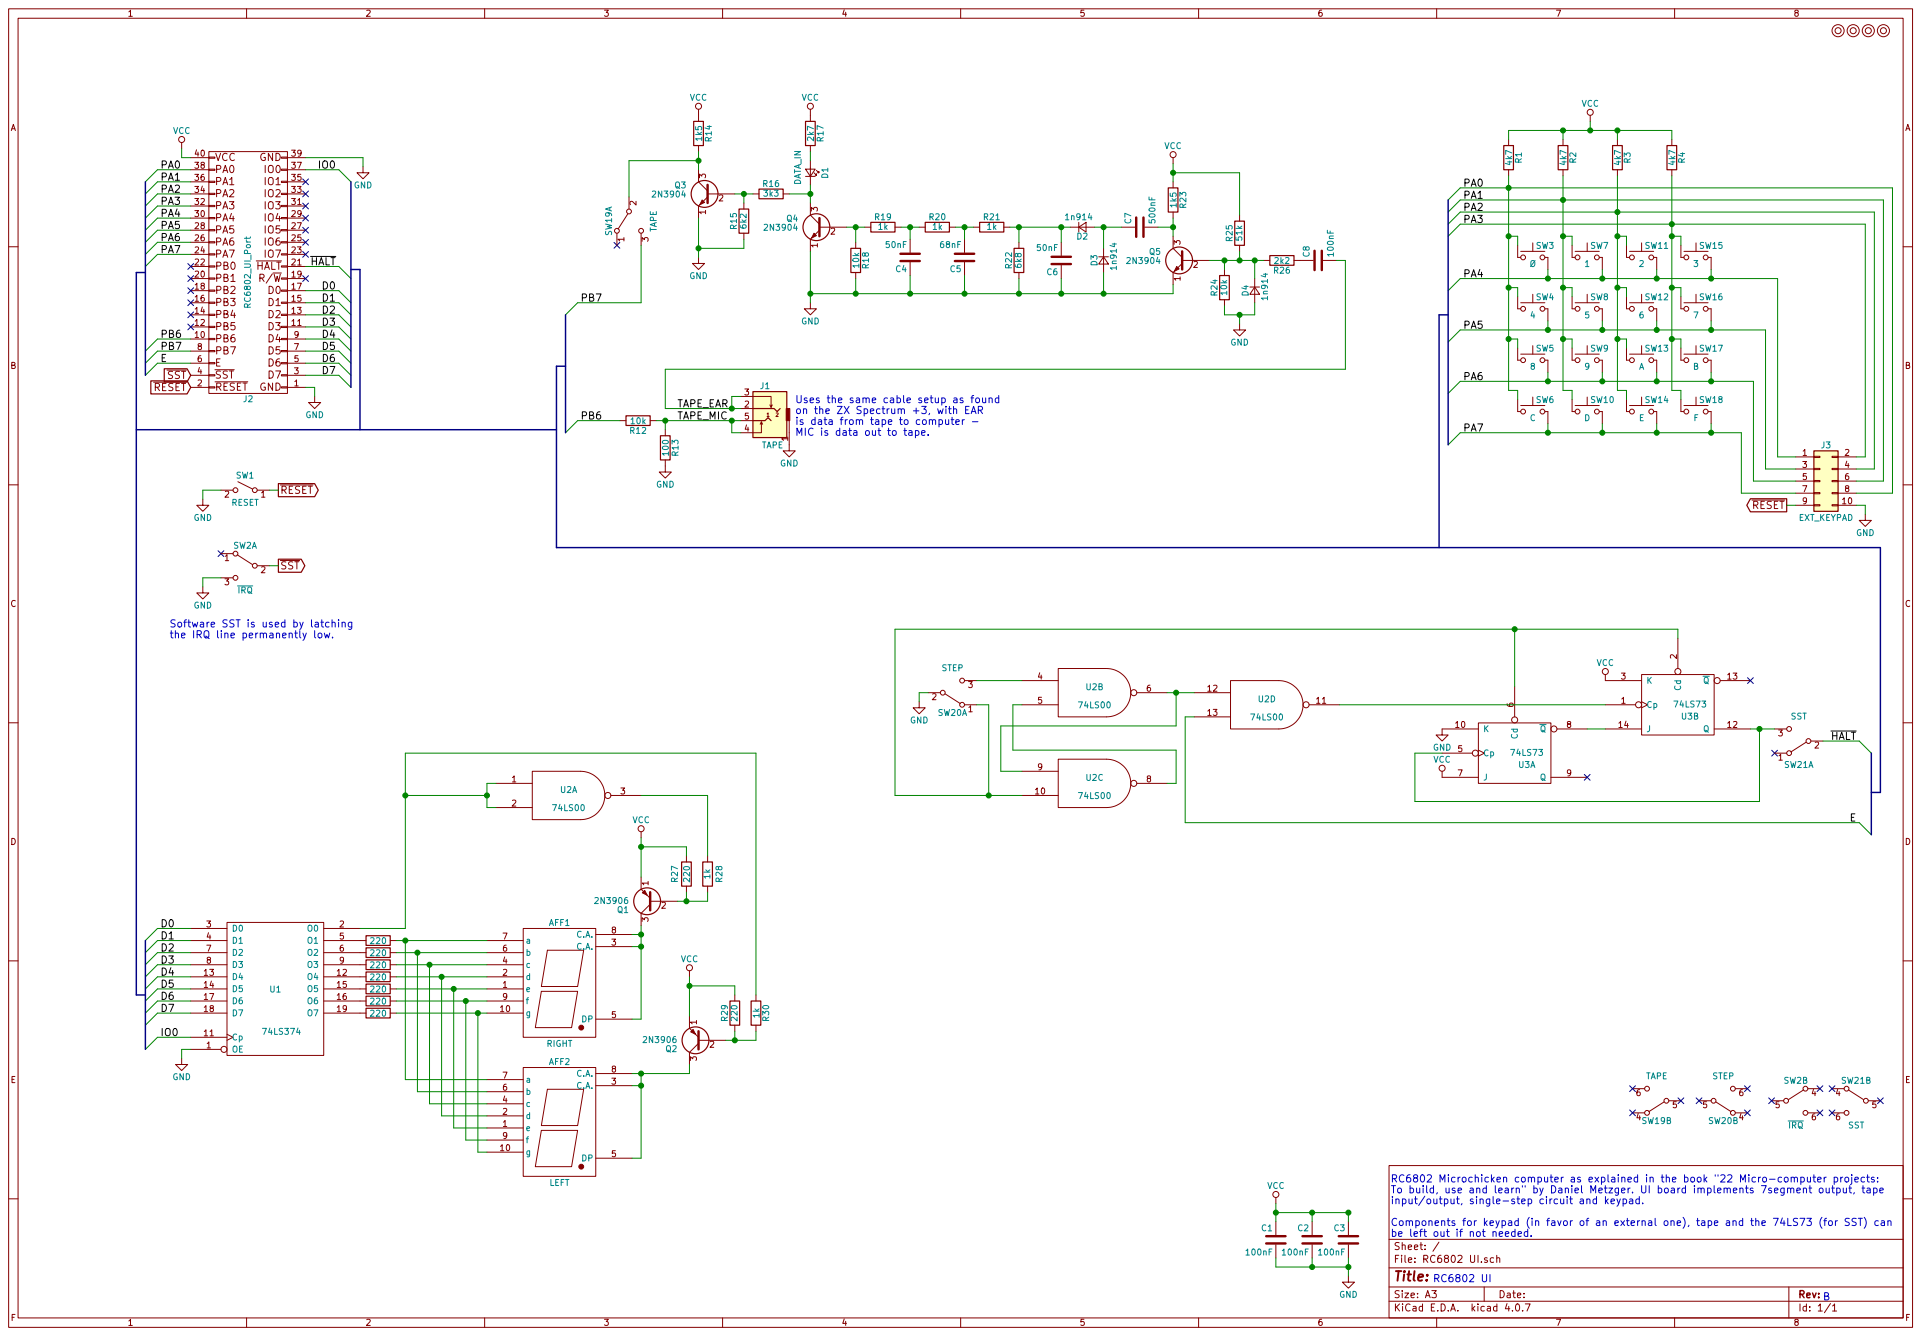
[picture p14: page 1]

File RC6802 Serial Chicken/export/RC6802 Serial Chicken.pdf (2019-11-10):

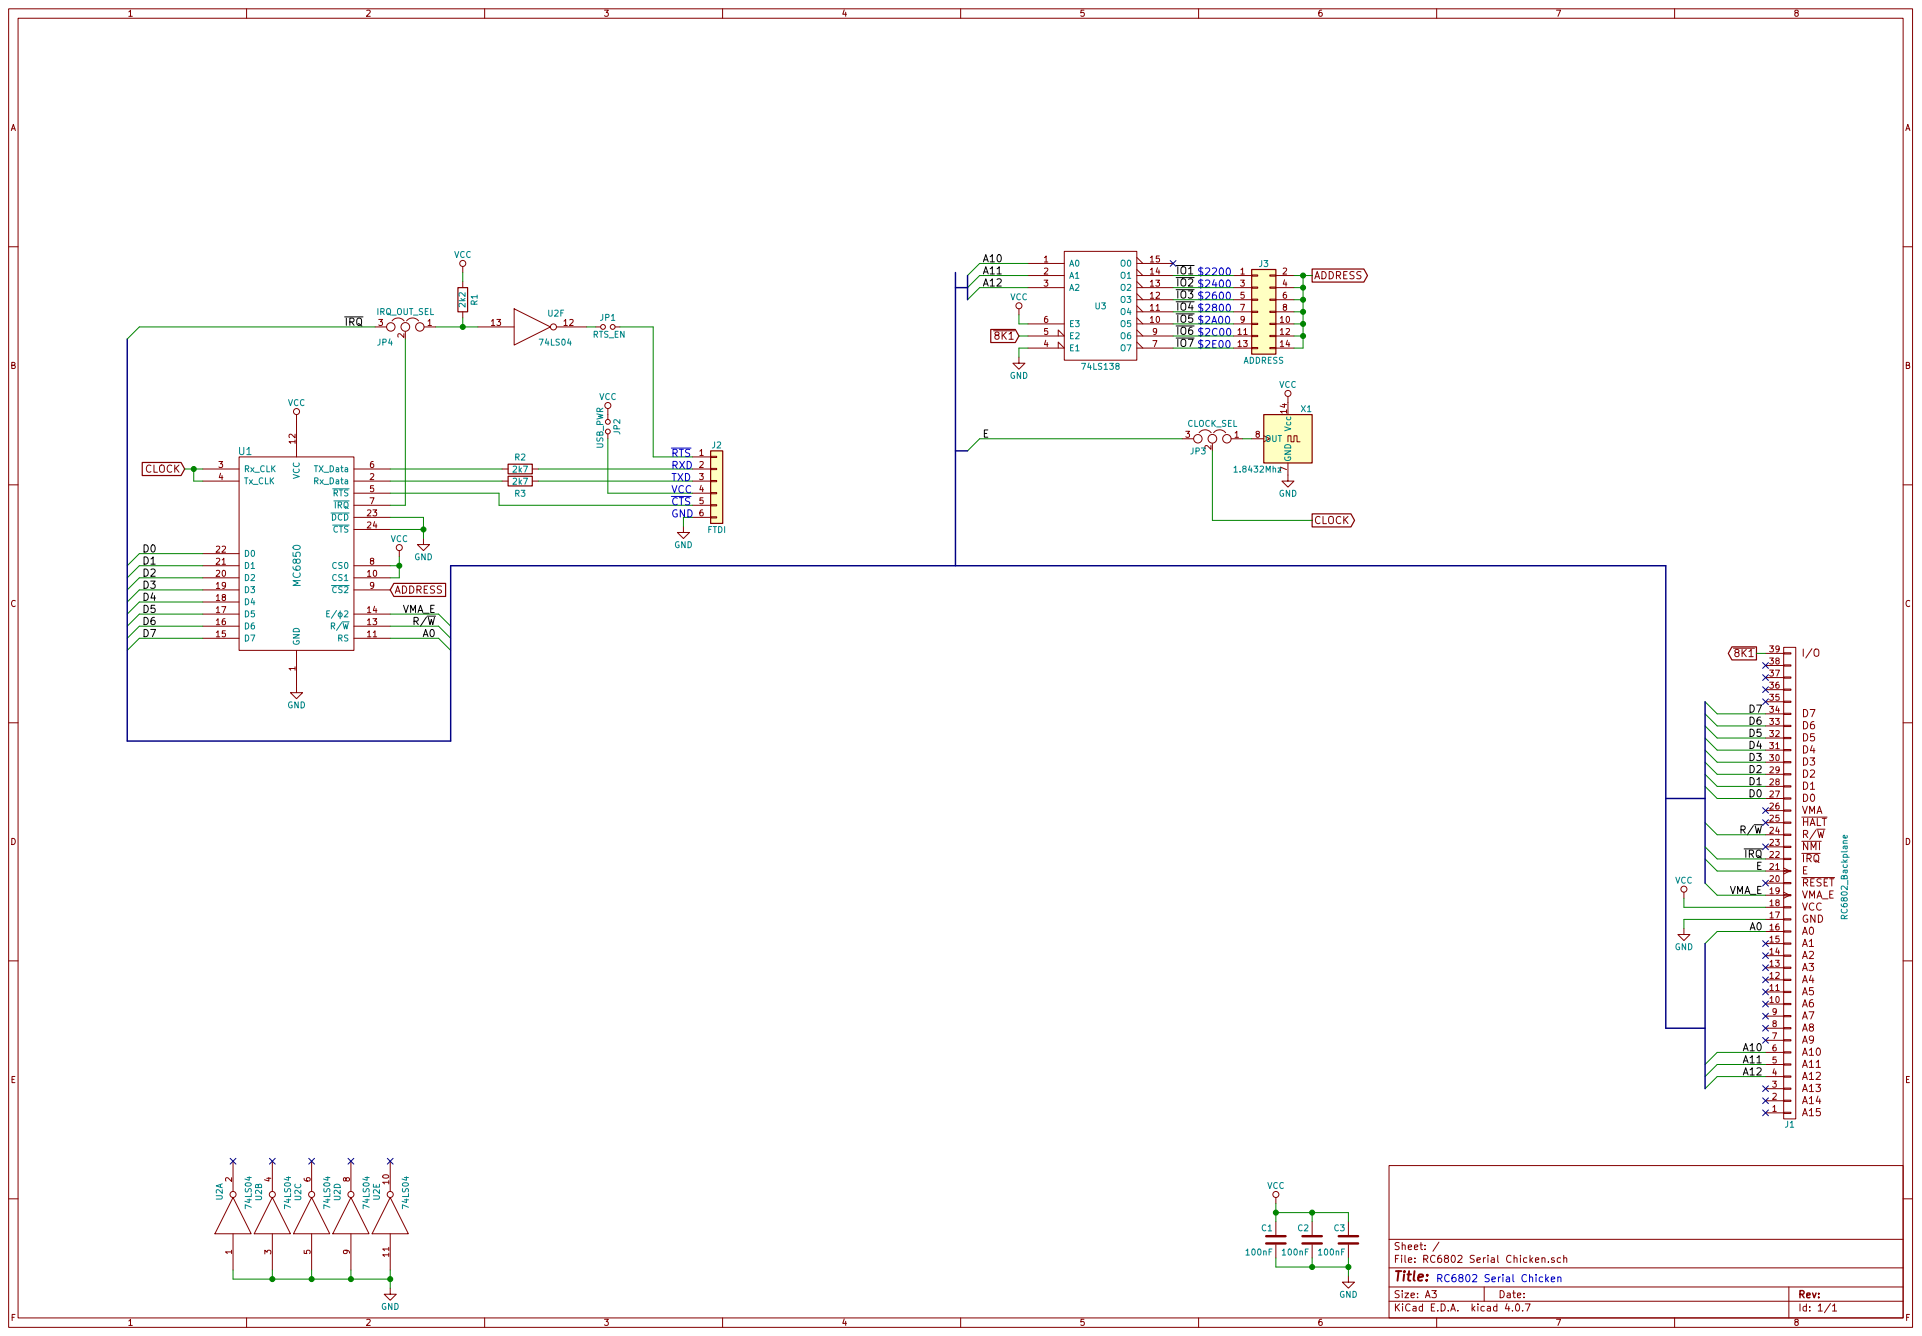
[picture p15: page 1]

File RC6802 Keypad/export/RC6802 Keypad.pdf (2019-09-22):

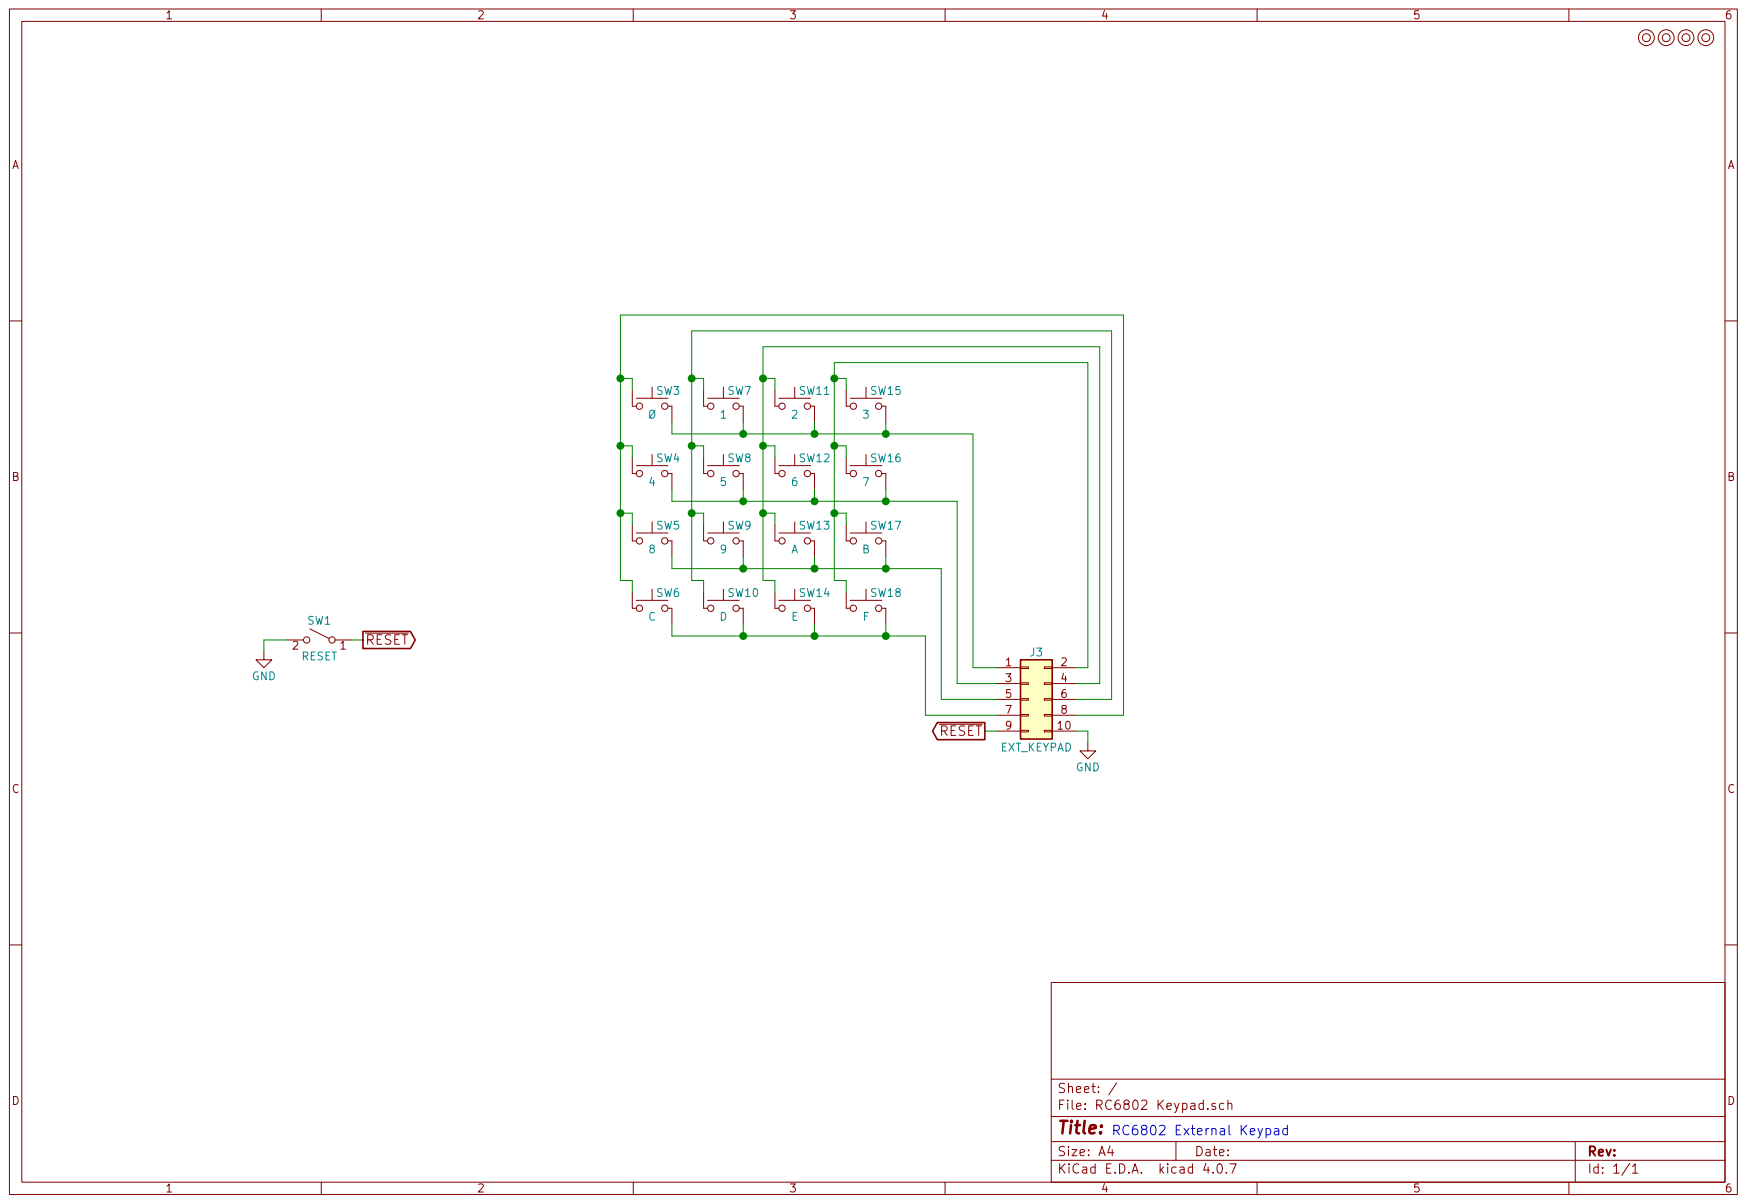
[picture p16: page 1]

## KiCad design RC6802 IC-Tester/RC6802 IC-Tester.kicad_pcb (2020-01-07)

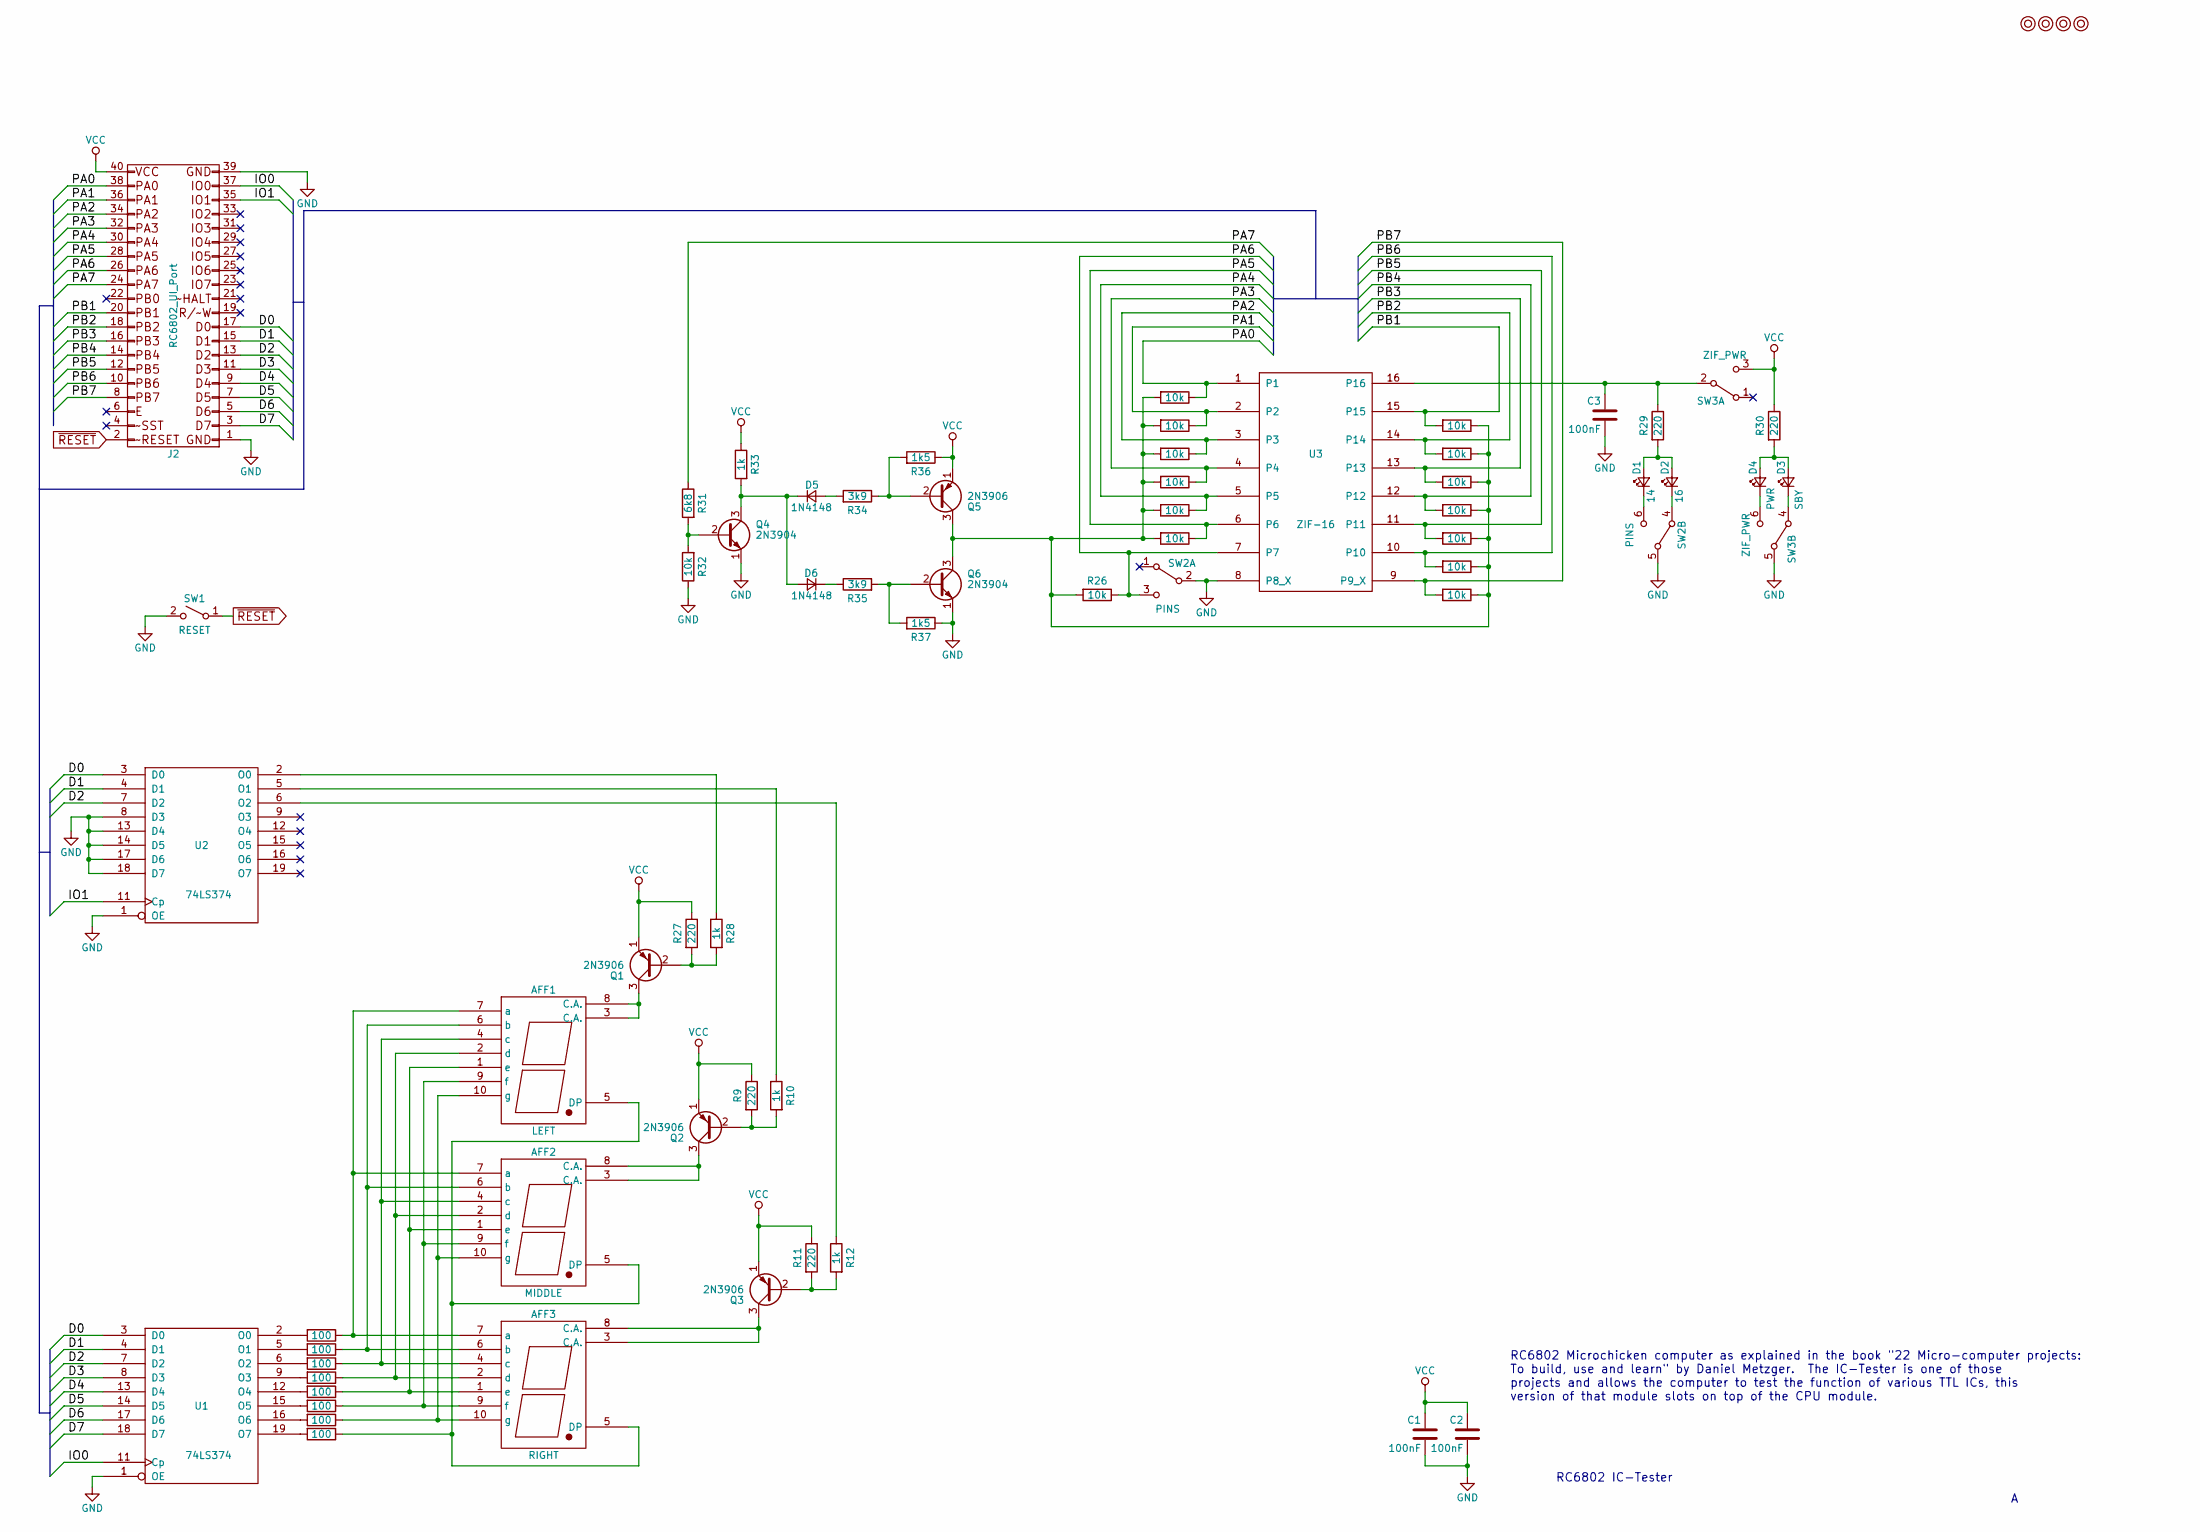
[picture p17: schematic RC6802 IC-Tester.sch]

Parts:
AFF1: LEFT; 7SegmentLED_LTS6760_LTS6780
AFF2: MIDDLE; 7SegmentLED_LTS6760_LTS6780
AFF3: RIGHT; 7SegmentLED_LTS6760_LTS6780
C1, C2, C3: 100nF; C_Disc_D4.7mm_W2.5mm_P5.00mm
D1: 14; LED_D5.0mm
D2: 16; LED_D5.0mm
D3: SBY; LED_D5.0mm
D4: PWR; LED_D5.0mm
D5, D6: 1N4148; D_DO-35_SOD27_P7.62mm_Horizontal
J2: RC6802_UI_Port; Pin_Header_Straight_2x20_Pitch2.54mm
M1, M2, M3, M4: Mounting; 1pin
Q1, Q2, Q3, Q5: 2N3906; TO-92_Molded_Narrow
Q4, Q6: 2N3904; TO-92_Molded_Narrow
R1, R2, R3, R4, R5, R6, R7, R8: 100; R_Axial_DIN0207_L6.3mm_D2.5mm_P10.16mm_Horizontal
R9, R11, R27, R29, R30: 220; R_Axial_DIN0207_L6.3mm_D2.5mm_P10.16mm_Horizontal
R10, R12, R28, R33: 1k; R_Axial_DIN0207_L6.3mm_D2.5mm_P10.16mm_Horizontal
R13, R14, R15, R16, R17, R18, R19, R20, R21, R22, R23, R24, R25, R26, R32: 10k; R_Axial_DIN0207_L6.3mm_D2.5mm_P10.16mm_Horizontal
R31: 6k8; R_Axial_DIN0207_L6.3mm_D2.5mm_P10.16mm_Horizontal
R34, R35: 3k9; R_Axial_DIN0207_L6.3mm_D2.5mm_P10.16mm_Horizontal
R36, R37: 1k5; R_Axial_DIN0207_L6.3mm_D2.5mm_P10.16mm_Horizontal
SW1: RESET; SW_PUSH_6mm
SW2: PINS; dpdt_switch_black
SW3: ZIF_PWR; dpdt_switch_black
U1, U2: 74LS374; DIP-20_W7.62mm_Socket
U3: ZIF-16

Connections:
/D0: J2.17, U1.3 (D0), U2.3 (D0)
/D1: J2.15, U1.4 (D1), U2.4 (D1)
/D2: J2.13, U1.7 (D2), U2.7 (D2)
/D3: J2.11, U1.8 (D3)
/D4: J2.9, U1.13 (D4)
/D5: J2.7, U1.14 (D5)
/D6: J2.5, U1.17 (D6)
/D7: J2.3, U1.18 (D7)
/IO0: J2.37, U1.11 (Cp)
/IO1: J2.35, U2.11 (Cp)
/PA0: J2.38, R13.1, U3.1
/PA1: J2.36, R14.1, U3.2
/PA2: J2.34, R15.1, U3.3
/PA3: J2.32, R16.1, U3.4
/PA4: J2.30, R17.1, U3.5
/PA5: J2.28, R18.1, U3.6
/PA6: J2.26, R26.1, SW2.3 (C), U3.7
/PA7: J2.24, R31.1
/PB1: J2.20, R19.2, U3.15
/PB2: J2.18, R20.2, U3.14
/PB3: J2.16, R21.2, U3.13
/PB4: J2.14, R22.2, U3.12
/PB5: J2.12, R23.2, U3.11
/PB6: J2.10, R24.2, U3.10
/PB7: J2.8, R25.2, U3.9 (P9_X)
GND: C1.2, C2.2, C3.2, J2.1, J2.39, Q4.1 (E), Q6.1 (E), R32.1, R37.1, SW1.2 (B), SW2.2 (B), SW2.5 (B), SW3.5 (B), U1.1 (OE), U1.10 (GND), U2.1 (OE), U2.8 (D3), U2.10 (GND), U2.13 (D4), U2.14 (D5), U2.17 (D6), U2.18 (D7), U3.8 (P8_X)
unnamed: AFF1.1 (e), AFF2.1 (e), AFF3.1 (e), R5.1
unnamed: AFF1.2 (d), AFF2.2 (d), AFF3.2 (d), R4.1
unnamed: AFF1.3 (C.A.), AFF1.8 (C.A.), Q1.3 (C)
unnamed: AFF1.4 (c), AFF2.4 (c), AFF3.4 (c), R3.1
unnamed: AFF1.5 (DP), AFF2.5 (DP), AFF3.5 (DP), R8.1
unnamed: AFF1.6 (b), AFF2.6 (b), AFF3.6 (b), R2.1
unnamed: AFF1.7 (a), AFF2.7 (a), AFF3.7 (a), R1.1
unnamed: AFF1.9 (f), AFF2.9 (f), AFF3.9 (f), R6.1
unnamed: AFF1.10 (g), AFF2.10 (g), AFF3.10 (g), R7.1
unnamed: AFF2.3 (C.A.), AFF2.8 (C.A.), Q2.3 (C)
unnamed: AFF3.3 (C.A.), AFF3.8 (C.A.), Q3.3 (C)
unnamed: C3.1, R29.1, SW3.2 (B), U3.16
unnamed: D1.1 (K), SW2.6 (C)
unnamed: D1.2 (A), D2.2 (A), R29.2
unnamed: D2.1 (K), SW2.4 (A)
unnamed: D3.1 (K), SW3.4 (A)
unnamed: D3.2 (A), D4.2 (A), R30.2
unnamed: D4.1 (K), SW3.6 (C)
unnamed: D5.1 (K), D6.2 (A), Q4.3 (C), R33.2
unnamed: D5.2 (A), R34.2
unnamed: D6.1 (K), R35.1
unnamed: Q1.2 (B), R27.2, R28.2
unnamed: Q2.2 (B), R9.2, R10.2
unnamed: Q3.2 (B), R11.2, R12.2
unnamed: Q4.2 (B), R31.2, R32.2
unnamed: Q5.2 (B), R34.1, R36.2
unnamed: Q5.3 (C), Q6.3 (C), R13.2, R14.2, R15.2, R16.2, R17.2, R18.2, R19.1, R20.1, R21.1, R22.1, R23.1, R24.1, R25.1, R26.2
unnamed: Q6.2 (B), R35.2, R37.2
unnamed: R1.2, U1.2 (O0)
unnamed: R2.2, U1.5 (O1)
unnamed: R3.2, U1.6 (O2)
unnamed: R4.2, U1.9 (O3)
unnamed: R5.2, U1.12 (O4)
unnamed: R6.2, U1.15 (O5)
unnamed: R7.2, U1.16 (O6)
unnamed: R8.2, U1.19 (O7)
unnamed: R10.1, U2.5 (O1)
unnamed: R12.1, U2.6 (O2)
unnamed: R28.1, U2.2 (O0)
VCC: C1.1, C2.1, J2.40, Q1.1 (E), Q2.1 (E), Q3.1 (E), Q5.1 (E), R9.1, R11.1, R27.1, R30.1, R33.1, R36.1, SW3.3 (C), U1.20 (VCC), U2.20 (VCC)
~RESET: J2.2, SW1.1 (A)

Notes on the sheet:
RC6802 IC-Tester
RC6802 Microchicken computer as explained in the book "22 Micro-computer projects: To build, use and learn" by Daniel Metzger. The IC-Tester is one of those projects and allows the computer to test the function of various TTL ICs, this version of that module slots on top of the CPU module.

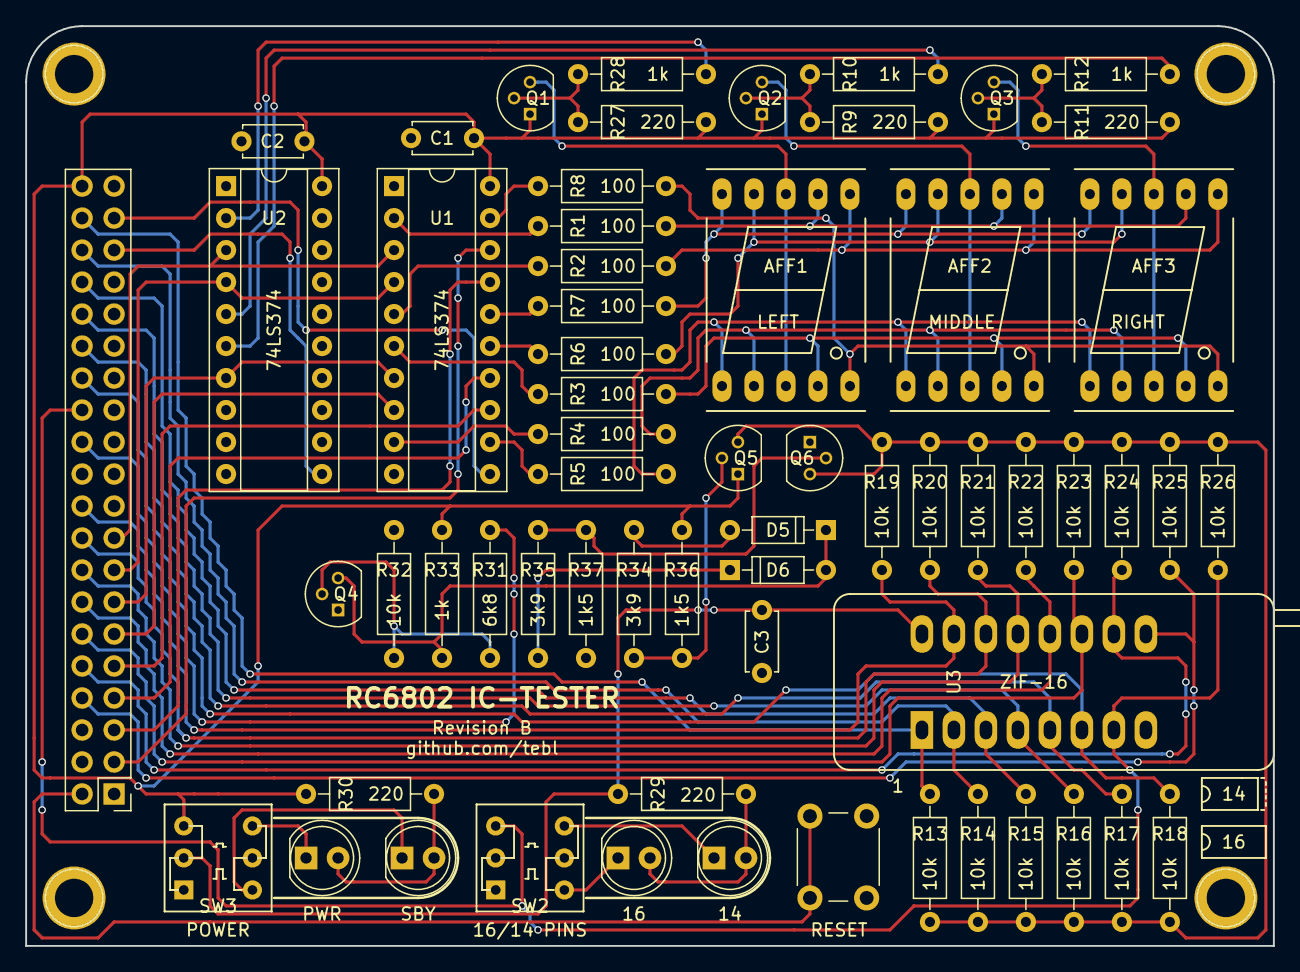
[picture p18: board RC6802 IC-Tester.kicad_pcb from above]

Board: 2 copper layers, 99.1 x 73.0 mm, 66 parts (0 on the bottom side), 67 nets.

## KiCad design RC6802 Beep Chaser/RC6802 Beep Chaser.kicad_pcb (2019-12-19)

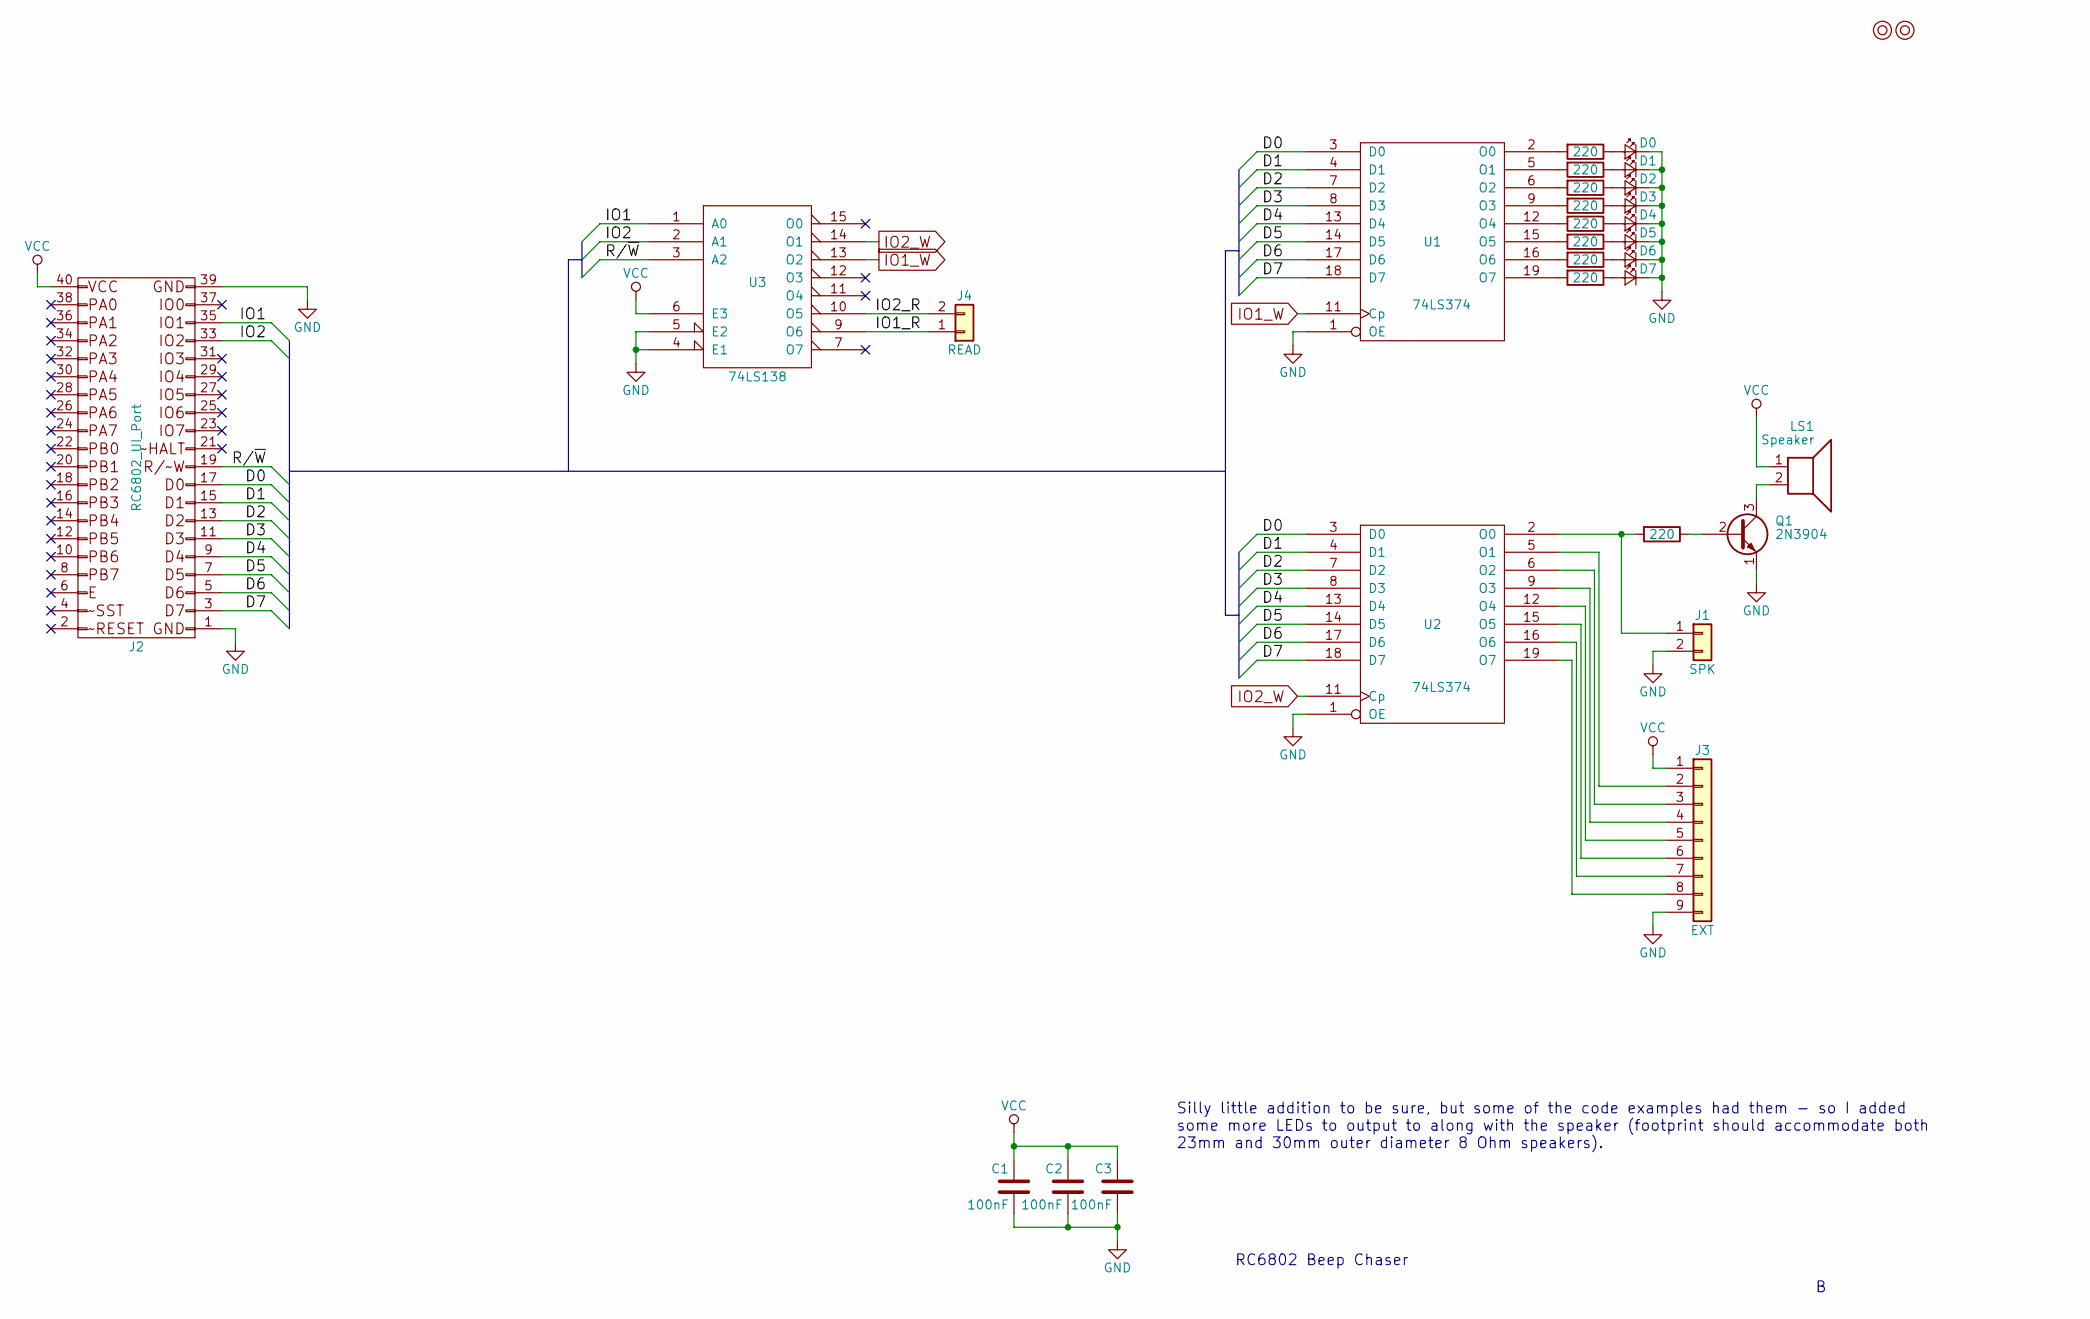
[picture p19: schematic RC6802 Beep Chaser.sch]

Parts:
C1, C2, C3: 100nF; C_Disc_D4.7mm_W2.5mm_P5.00mm
D0, D1, D2, D3, D4, D5, D6, D7: LED; LED_D5.0mm
J1: SPK; Pin_Header_Straight_1x02_Pitch2.54mm
J2: RC6802_UI_Port; Pin_Header_Straight_2x20_Pitch2.54mm
J3: EXT; Pin_Header_Straight_1x09_Pitch2.54mm
J4: READ; Pin_Header_Straight_1x02_Pitch2.54mm
LS1: Speaker; Mini_Speaker
M3, M4: Mounting; 1pin
Q1: 2N3904; TO-92_Inline_Wide
R1, R4, R5, R6, R7, R8, R9, R10, R11: 220; R_Axial_DIN0207_L6.3mm_D2.5mm_P10.16mm_Horizontal
U1, U2: 74LS374; DIP-20_W7.62mm_Socket
U3: 74LS138; DIP-16_W7.62mm_Socket

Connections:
/D0: J2.17, U1.3 (D0), U2.3 (D0)
/D1: J2.15, U1.4 (D1), U2.4 (D1)
/D2: J2.13, U1.7 (D2), U2.7 (D2)
/D3: J2.11, U1.8 (D3), U2.8 (D3)
/D4: J2.9, U1.13 (D4), U2.13 (D4)
/D5: J2.7, U1.14 (D5), U2.14 (D5)
/D6: J2.5, U1.17 (D6), U2.17 (D6)
/D7: J2.3, U1.18 (D7), U2.18 (D7)
/IO1: J2.35, U3.1 (A0)
/IO1_R: J4.1, U3.9 (O6)
/IO2: J2.33, U3.2 (A1)
/IO2_R: J4.2, U3.10 (O5)
/R/~W: J2.19, U3.3 (A2)
GND: C1.2, C2.2, C3.2, D0.1 (K), D1.1 (K), D2.1 (K), D3.1 (K), D4.1 (K), D5.1 (K), D6.1 (K), D7.1 (K), J1.2, J2.1, J2.39, J3.9, Q1.1 (E), U1.1 (OE), U1.10 (GND), U2.1 (OE), U2.10 (GND), U3.4 (E1), U3.5 (E2), U3.8 (GND)
IO1_W: U1.11 (Cp), U3.13 (O2)
IO2_W: U2.11 (Cp), U3.14 (O1)
unnamed: D0.2 (A), R4.1
unnamed: D1.2 (A), R5.1
unnamed: D2.2 (A), R6.1
unnamed: D3.2 (A), R7.1
unnamed: D4.2 (A), R8.1
unnamed: D5.2 (A), R9.1
unnamed: D6.2 (A), R10.1
unnamed: D7.2 (A), R11.1
unnamed: J1.1, R1.2, U2.2 (O0)
unnamed: J3.2, U2.5 (O1)
unnamed: J3.3, U2.6 (O2)
unnamed: J3.4, U2.9 (O3)
unnamed: J3.5, U2.12 (O4)
unnamed: J3.6, U2.15 (O5)
unnamed: J3.7, U2.16 (O6)
unnamed: J3.8, U2.19 (O7)
unnamed: LS1.2, Q1.3 (C)
unnamed: Q1.2 (B), R1.1
unnamed: R4.2, U1.2 (O0)
unnamed: R5.2, U1.5 (O1)
unnamed: R6.2, U1.6 (O2)
unnamed: R7.2, U1.9 (O3)
unnamed: R8.2, U1.12 (O4)
unnamed: R9.2, U1.15 (O5)
unnamed: R10.2, U1.16 (O6)
unnamed: R11.2, U1.19 (O7)
VCC: C1.1, C2.1, C3.1, J2.40, J3.1, LS1.1, U1.20 (VCC), U2.20 (VCC), U3.6 (E3), U3.16 (VCC)

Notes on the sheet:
RC6802 Beep Chaser
Silly little addition to be sure, but some of the code examples had them - so I added some more LEDs to output to along with the speaker (footprint should accommodate both 23mm and 30mm outer diameter 8 Ohm speakers).

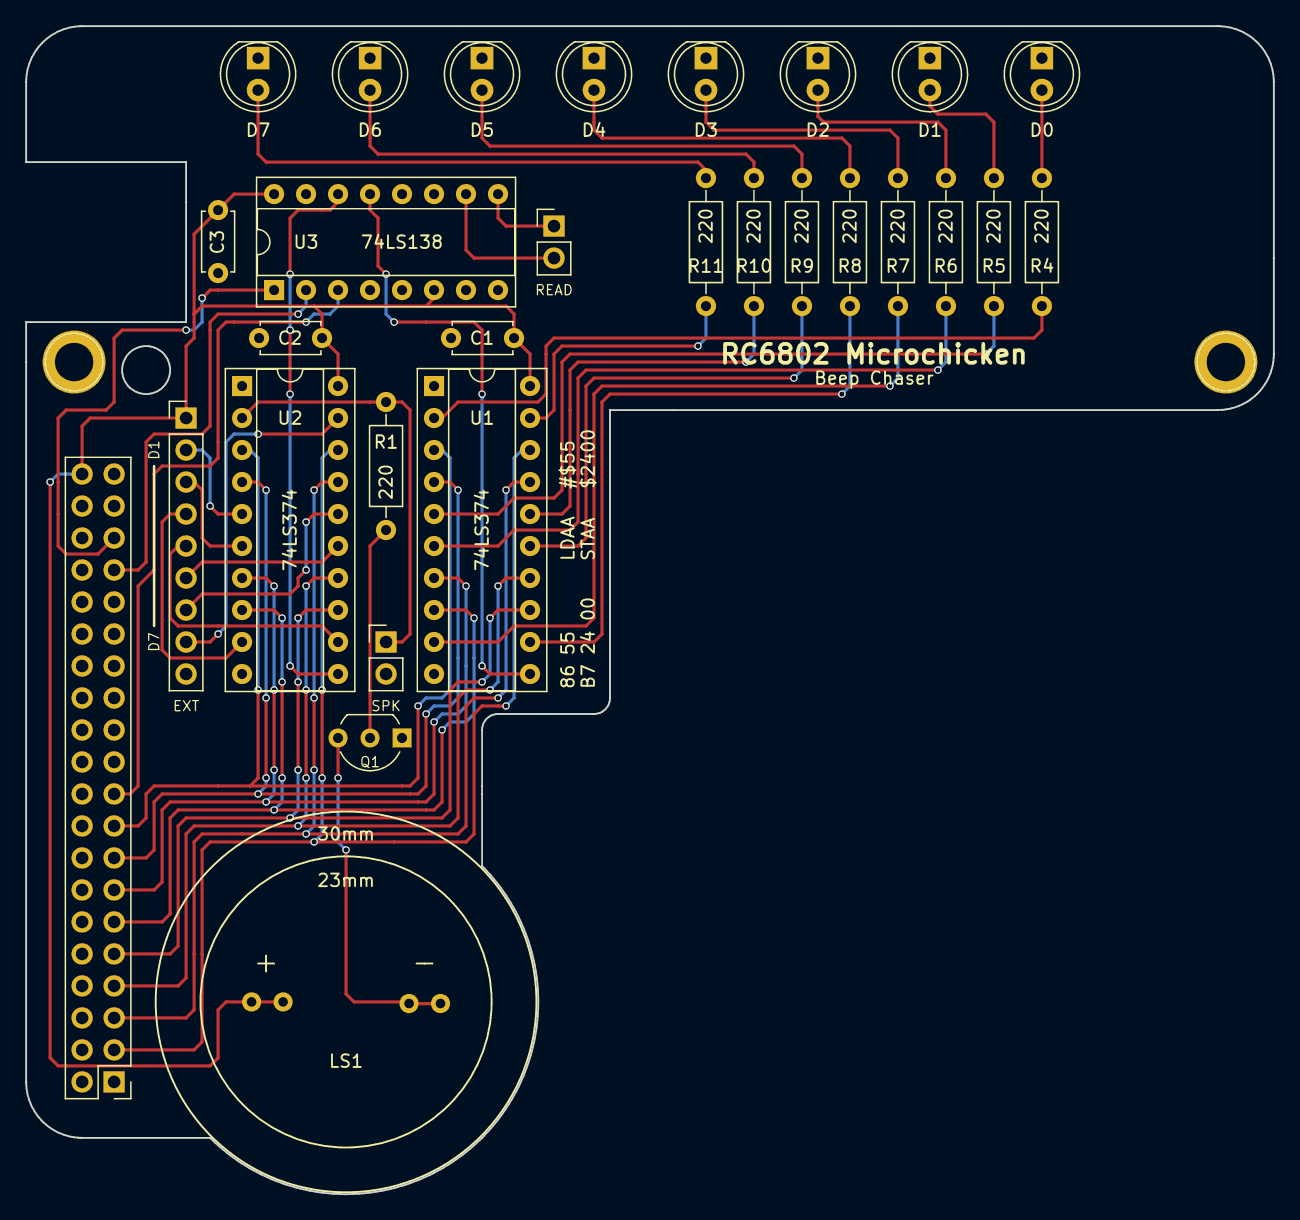
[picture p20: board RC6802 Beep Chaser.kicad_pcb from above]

Board: 2 copper layers, 99.1 x 92.7 mm, 31 parts (0 on the bottom side), 43 nets.

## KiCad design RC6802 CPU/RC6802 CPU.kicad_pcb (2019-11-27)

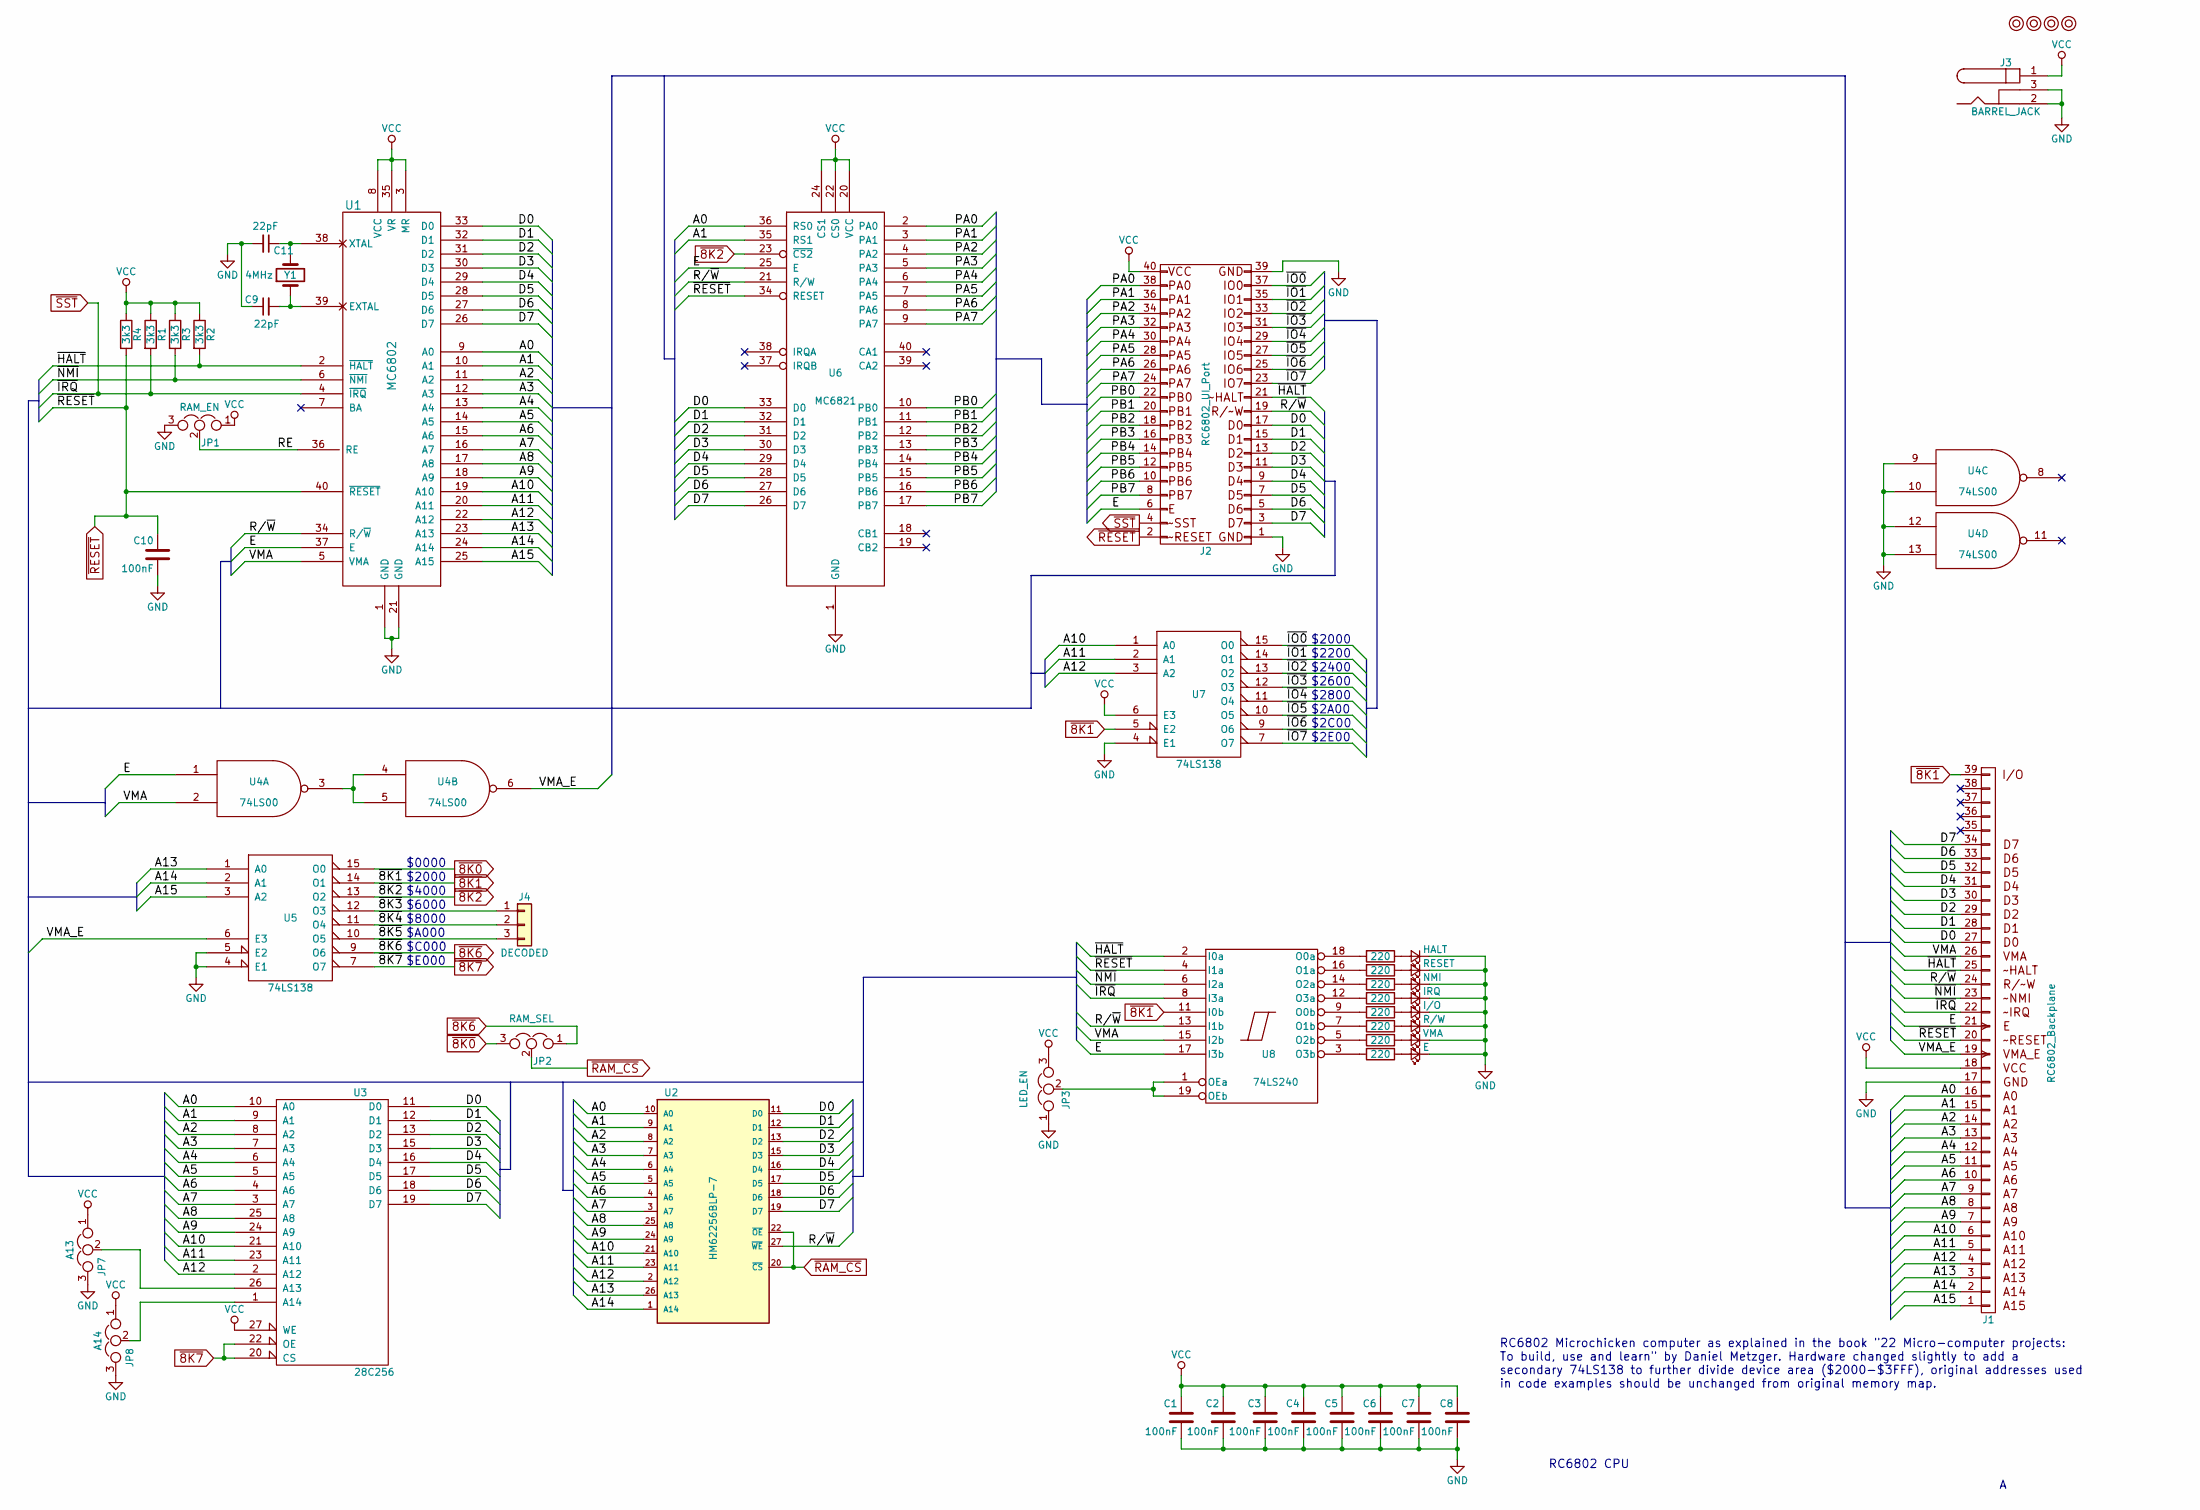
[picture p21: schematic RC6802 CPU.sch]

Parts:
C1, C2, C3, C4, C5, C6, C7, C8, C10: 100nF; C_Disc_D4.7mm_W2.5mm_P5.00mm
C9, C11: 22pF; C_Disc_D4.7mm_W2.5mm_P5.00mm
D1: HALT; LED_D5.0mm
D2: RESET; LED_D5.0mm
D3: NMI; LED_D5.0mm
D4: IRQ; LED_D5.0mm
D5: I/O; LED_D5.0mm
D6: R/W; LED_D5.0mm
D7: VMA; LED_D5.0mm
D8: E; LED_D5.0mm
J1: RC6802_Backplane; Pin_Header_Angled_1x39_Pitch2.54mm
J2: RC6802_UI_Port; Pin_Header_Straight_2x20_Pitch2.54mm
J3: BARREL_JACK
J4: DECODED; Pin_Header_Straight_1x03_Pitch2.54mm
JP1: RAM_EN; Pin_Header_Straight_1x03_Pitch2.54mm
JP2: RAM_SEL; Pin_Header_Straight_1x03_Pitch2.54mm
JP3: LED_EN; Pin_Header_Straight_1x03_Pitch2.54mm
JP7: A13; Pin_Header_Straight_1x03_Pitch2.54mm
JP8: A14; Pin_Header_Straight_1x03_Pitch2.54mm
M1, M2, M3, M4: Mounting; 1pin
R1, R2, R3, R4: 3k3; R_Axial_DIN0207_L6.3mm_D2.5mm_P10.16mm_Horizontal
R5, R6, R7, R8, R9, R10, R11, R12: 220; R_Axial_DIN0207_L6.3mm_D2.5mm_P7.62mm_Horizontal
U1: MC6802; DIP-40_W15.24mm_Socket
U2: HM62256BLP-7; DIP-28_W15.24mm_Socket
U3: 28C256; DIP-28_W15.24mm_Socket
U4: 74LS00; DIP-14_W7.62mm_Socket
U5, U7: 74LS138; DIP-16_W7.62mm_Socket
U6: MC6821; DIP-40_W15.24mm_Socket
U8: 74LS240; DIP-20_W7.62mm_Socket
Y1: 4MHz; Crystal_HC49-U_Vertical

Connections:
/A0: J1.16 (A0), U1.9 (A0), U2.10 (A0), U3.10 (A0), U6.36 (RS0)
/A1: J1.15 (A1), U1.10 (A1), U2.9 (A1), U3.9 (A1), U6.35 (RS1)
/A2: J1.14 (A2), U1.11 (A2), U2.8 (A2), U3.8 (A2)
/A3: J1.13 (A3), U1.12 (A3), U2.7 (A3), U3.7 (A3)
/A4: J1.12 (A4), U1.13 (A4), U2.6 (A4), U3.6 (A4)
/A5: J1.11 (A5), U1.14 (A5), U2.5 (A5), U3.5 (A5)
/A6: J1.10 (A6), U1.15 (A6), U2.4 (A6), U3.4 (A6)
/A7: J1.9 (A7), U1.16 (A7), U2.3 (A7), U3.3 (A7)
/A8: J1.8 (A8), U1.17 (A8), U2.25 (A8), U3.25 (A8)
/A9: J1.7 (A9), U1.18 (A9), U2.24 (A9), U3.24 (A9)
/A10: J1.6 (A10), U1.19 (A10), U2.21 (A10), U3.21 (A10), U7.1 (A0)
/A11: J1.5 (A11), U1.20 (A11), U2.23 (A11), U3.23 (A11), U7.2 (A1)
/A12: J1.4 (A12), U1.22 (A12), U2.2 (A12), U3.2 (A12), U7.3 (A2)
/A13: J1.3 (A13), U1.23 (A13), U2.26 (A13), U5.1 (A0)
/A14: J1.2 (A14), U1.24 (A14), U2.1 (A14), U5.2 (A1)
/A15: J1.1 (A15), U1.25 (A15), U5.3 (A2)
/D0: J1.27 (D0), J2.17, U1.33 (D0), U2.11 (D0), U3.11 (D0), U6.33 (D0)
/D1: J1.28 (D1), J2.15, U1.32 (D1), U2.12 (D1), U3.12 (D1), U6.32 (D1)
/D2: J1.29 (D2), J2.13, U1.31 (D2), U2.13 (D2), U3.13 (D2), U6.31 (D2)
/D3: J1.30 (D3), J2.11, U1.30 (D3), U2.15 (D3), U3.15 (D3), U6.30 (D3)
/D4: J1.31 (D4), J2.9, U1.29 (D4), U2.16 (D4), U3.16 (D4), U6.29 (D4)
/D5: J1.32 (D5), J2.7, U1.28 (D5), U2.17 (D5), U3.17 (D5), U6.28 (D5)
/D6: J1.33 (D6), J2.5, U1.27 (D6), U2.18 (D6), U3.18 (D6), U6.27 (D6)
/D7: J1.34 (D7), J2.3, U1.26 (D7), U2.19 (D7), U3.19 (D7), U6.26 (D7)
/E: J1.21 (PHI0), J2.6, U1.37 (E), U4.1, U6.25 (E), U8.17 (I3b)
/PA0: J2.38, U6.2 (PA0)
/PA1: J2.36, U6.3 (PA1)
/PA2: J2.34, U6.4 (PA2)
/PA3: J2.32, U6.5 (PA3)
/PA4: J2.30, U6.6 (PA4)
/PA5: J2.28, U6.7 (PA5)
/PA6: J2.26, U6.8 (PA6)
/PA7: J2.24, U6.9 (PA7)
/PB0: J2.22, U6.10 (PB0)
/PB1: J2.20, U6.11 (PB1)
/PB2: J2.18, U6.12 (PB2)
/PB3: J2.16, U6.13 (PB3)
/PB4: J2.14, U6.14 (PB4)
/PB5: J2.12, U6.15 (PB5)
/PB6: J2.10, U6.16 (PB6)
/PB7: J2.8, U6.17 (PB7)
/R/~W: J1.24 (RW), J2.19, U1.34 (R/~W), U2.27 (~WE), U6.21 (R/W), U8.13 (I1b)
/RE: JP1.2, U1.36 (RE)
/VMA: J1.26 (SYNC), U1.5 (VMA), U4.2, U8.15 (I2b)
/VMA_E: J1.19 (PHI2), U4.6, U5.6 (E3)
/~8K3: J4.1, U5.12 (O3)
/~8K4: J4.2, U5.11 (O4)
/~8K5: J4.3, U5.10 (O5)
/~HALT: J1.25 (READY), J2.21, R2.2, U1.2 (~HALT), U8.2 (I0a)
/~IO0: J2.37, U7.15 (O0)
/~IO1: J2.35, U7.14 (O1)
/~IO2: J2.33, U7.13 (O2)
/~IO3: J2.31, U7.12 (O3)
/~IO4: J2.29, U7.11 (O4)
/~IO5: J2.27, U7.10 (O5)
/~IO6: J2.25, U7.9 (O6)
/~IO7: J2.23, U7.7 (O7)
/~NMI: J1.23 (PHI1), R3.2, U1.6 (~NMI), U8.6 (I2a)
GND: C1.2, C2.2, C3.2, C4.2, C5.2, C6.2, C7.2, C8.2, C9.1, C10.2, C11.2, D1.1 (K), D2.1 (K), D3.1 (K), D4.1 (K), D5.1 (K), D6.1 (K), D7.1 (K), D8.1 (K), J1.17, J2.1, J2.39, J3.2, J3.3, JP1.3, JP3.1, JP7.3, JP8.3, U1.1 (GND), U1.21 (GND), U2.14 (GND), U3.14 (GND), U4.7 (GND), U4.9, U4.10, U4.12, U4.13, U5.4 (E1), U5.5 (E2), U5.8 (GND), U6.1 (GND), U7.4 (E1), U7.8 (GND), U8.10 (GND)
unnamed: C9.2, U1.39 (EXTAL), Y1.1
unnamed: C11.1, U1.38 (XTAL), Y1.2
unnamed: D1.2 (A), R8.1
unnamed: D2.2 (A), R7.1
unnamed: D3.2 (A), R6.1
unnamed: D4.2 (A), R5.1
unnamed: D5.2 (A), R12.1
unnamed: D6.2 (A), R11.1
unnamed: D7.2 (A), R10.1
unnamed: D8.2 (A), R9.1
unnamed: JP3.2, U8.1 (OEa), U8.19 (OEb)
unnamed: JP7.2, U3.26 (A13)
unnamed: JP8.2, U3.1 (A14)
unnamed: R5.2, U8.12 (O3a)
unnamed: R6.2, U8.14 (O2a)
unnamed: R7.2, U8.16 (O1a)
unnamed: R8.2, U8.18 (O0a)
unnamed: R9.2, U8.3 (O3b)
unnamed: R10.2, U8.5 (O2b)
unnamed: R11.2, U8.7 (O1b)
unnamed: R12.2, U8.9 (O0b)
unnamed: U4.3, U4.4, U4.5
VCC: C1.1, C2.1, C3.1, C4.1, C5.1, C6.1, C7.1, C8.1, J1.18, J2.40, J3.1, JP1.1, JP3.3, JP7.1, JP8.1, R1.1, R2.1, R3.1, R4.1, U1.3 (MR), U1.8 (VCC), U1.35 (VR), U2.28 (VCC), U3.27 (WE), U3.28 (VCC), U4.14 (VCC), U5.16 (VCC), U6.20 (VCC), U6.22 (CS0), U6.24 (CS1), U7.6 (E3), U7.16 (VCC), U8.20 (VCC)
~8K0: JP2.3, U5.15 (O0)
~8K1: J1.39, U5.14 (O1), U7.5 (E2), U8.11 (I0b)
~8K2: U5.13 (O2), U6.23 (~CS2)
~8K6: JP2.1, U5.9 (O6)
~8K7: U3.20 (CS), U3.22 (OE), U5.7 (O7)
~RAM_CS: JP2.2, U2.20 (~CS), U2.22 (~OE)
~RESET: C10.1, J1.20 (RESET), J2.2, R4.2, U1.40 (~RESET), U6.34 (RESET), U8.4 (I1a)
~SST: J1.22 (IRQ), J2.4, R1.2, U1.4 (~IRQ), U8.8 (I3a)

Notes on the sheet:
RC6802 CPU
$0000
$2000
$4000
$6000
$8000
$A000
$C000
$E000
RC6802 Microchicken computer as explained in the book "22 Micro-computer projects: To build, use and learn" by Daniel Metzger. Hardware changed slightly to add a secondary 74LS138 to further divide device area ($2000-$3FFF), original addresses used in code examples should be unchanged from original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
$2200
$2400
$2600
$2800
$2A00
$2C00
$2E00

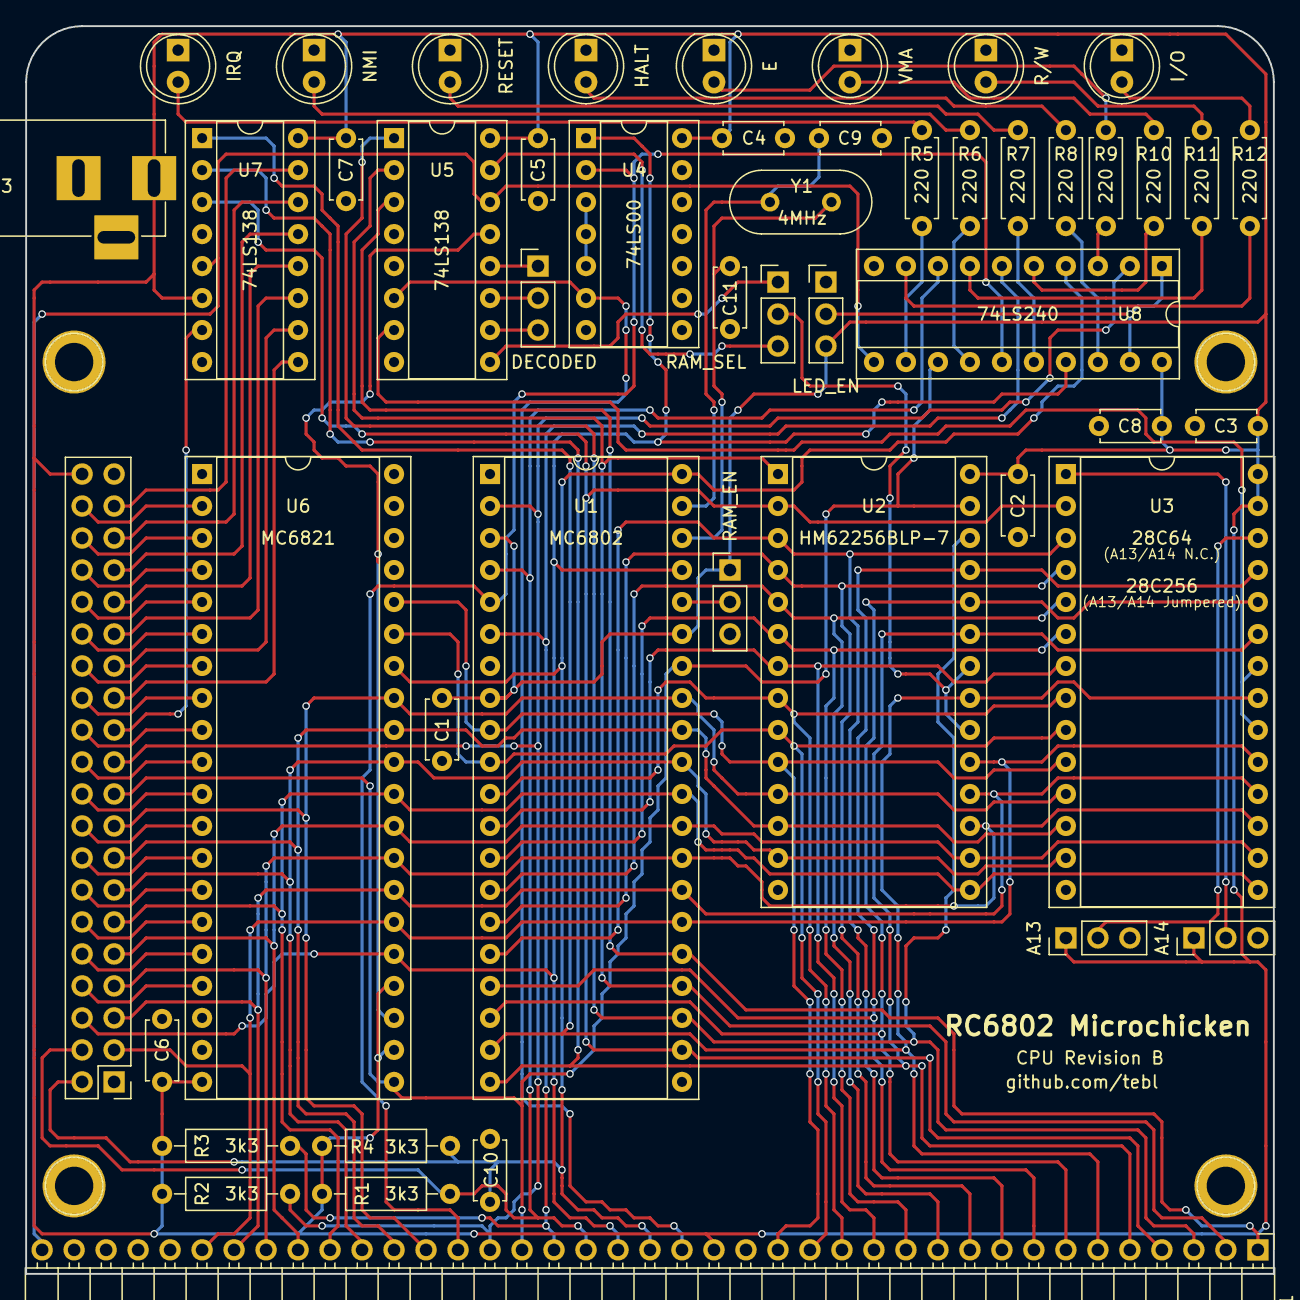
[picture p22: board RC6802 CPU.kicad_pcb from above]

Board: 2 copper layers, 99.1 x 99.1 mm, 53 parts (0 on the bottom side), 90 nets.

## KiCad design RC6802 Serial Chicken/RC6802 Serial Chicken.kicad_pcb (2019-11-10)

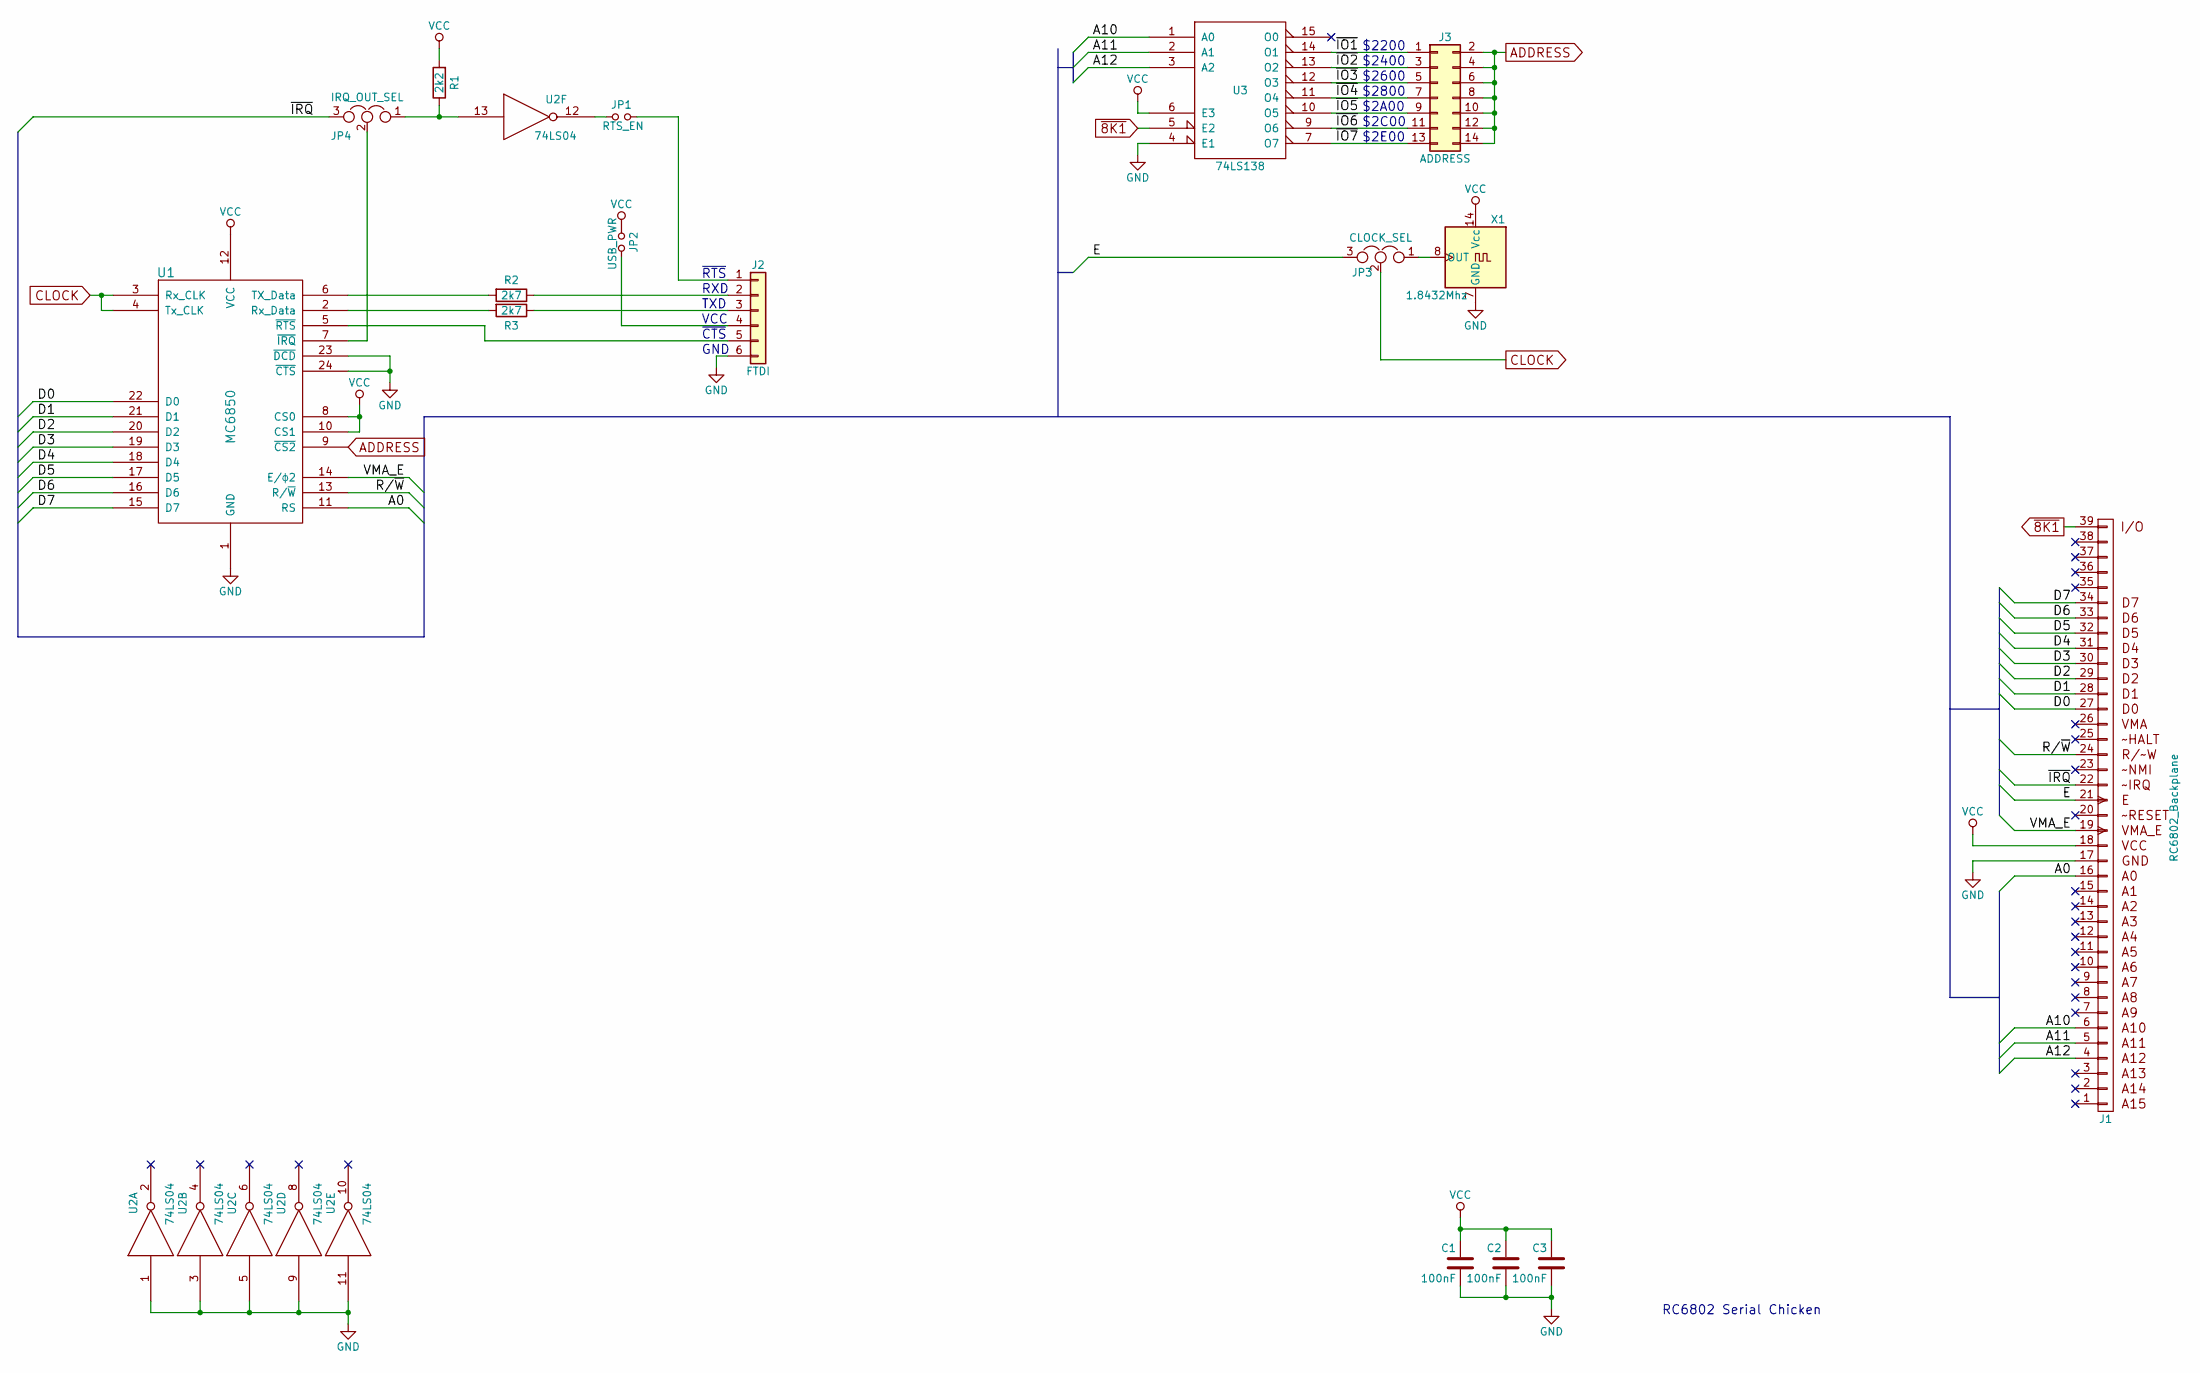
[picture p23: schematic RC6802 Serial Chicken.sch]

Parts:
C1, C2, C3: 100nF; C_Disc_D4.7mm_W2.5mm_P5.00mm
J1: RC6802_Backplane; Pin_Header_Angled_1x39_Pitch2.54mm
J2: FTDI; Pin_Header_Angled_1x06_Pitch2.54mm
J3: ADDRESS; Pin_Header_Straight_2x07_Pitch2.54mm
JP1: RTS_EN; Pin_Header_Straight_1x02_Pitch2.54mm
JP2: USB_PWR; Pin_Header_Straight_1x02_Pitch2.54mm
JP3: CLOCK_SEL; Pin_Header_Straight_1x03_Pitch2.54mm
JP4: IRQ_OUT_SEL; Pin_Header_Straight_1x03_Pitch2.54mm
R1: 2k2; R_Axial_DIN0207_L6.3mm_D2.5mm_P10.16mm_Horizontal
R2, R3: 2k7; R_Axial_DIN0207_L6.3mm_D2.5mm_P10.16mm_Horizontal
U1: MC6850; DIP-24_W15.24mm_Socket
U2: 74LS04; DIP-14_W7.62mm_Socket
U3: 74LS138; DIP-16_W7.62mm_Socket
X1: 1.8432Mhz; Oscillator_DIP-14

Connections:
/A0: J1.16 (A0), U1.11 (RS)
/A10: J1.6 (A10), U3.1 (A0)
/A11: J1.5 (A11), U3.2 (A1)
/A12: J1.4 (A12), U3.3 (A2)
/D0: J1.27 (D0), U1.22 (D0)
/D1: J1.28 (D1), U1.21 (D1)
/D2: J1.29 (D2), U1.20 (D2)
/D3: J1.30 (D3), U1.19 (D3)
/D4: J1.31 (D4), U1.18 (D4)
/D5: J1.32 (D5), U1.17 (D5)
/D6: J1.33 (D6), U1.16 (D6)
/D7: J1.34 (D7), U1.15 (D7)
/E: J1.21 (PHI0), JP3.3
/R/~W: J1.24 (RW), U1.13 (R/~W)
/VMA_E: J1.19 (PHI2), U1.14 (E/ϕ2)
/~IO1: J3.1, U3.14 (O1)
/~IO2: J3.3, U3.13 (O2)
/~IO3: J3.5, U3.12 (O3)
/~IO4: J3.7, U3.11 (O4)
/~IO5: J3.9, U3.10 (O5)
/~IO6: J3.11, U3.9 (O6)
/~IO7: J3.13, U3.7 (O7)
/~IRQ: J1.22 (IRQ), JP4.3
ADDRESS: J3.2, J3.4, J3.6, J3.8, J3.10, J3.12, J3.14, U1.9 (~CS2)
CLOCK: JP3.2, U1.3 (Rx_CLK), U1.4 (Tx_CLK)
GND: C1.2, C2.2, C3.2, J1.17, J2.6, U1.1 (GND), U1.23 (~DCD), U1.24 (~CTS), U2.1, U2.3, U2.5, U2.7 (GND), U2.9, U2.11, U3.4 (E1), U3.8 (GND), X1.7 (GND)
unnamed: J2.1, JP1.2
unnamed: J2.2, R2.1
unnamed: J2.3, R3.1
unnamed: J2.4, JP2.2
unnamed: J2.5, U1.5 (~RTS)
unnamed: JP1.1, U2.12
unnamed: JP3.1, X1.8 (OUT)
unnamed: JP4.1, R1.1, U2.13
unnamed: JP4.2, U1.7 (~IRQ)
unnamed: R2.2, U1.6 (TX_Data)
unnamed: R3.2, U1.2 (Rx_Data)
VCC: C1.1, C2.1, C3.1, J1.18, JP2.1, R1.2, U1.8 (CS0), U1.10 (CS1), U1.12 (VCC), U2.14 (VCC), U3.6 (E3), U3.16 (VCC), X1.14 (Vcc)
~8K1: J1.39, U3.5 (E2)

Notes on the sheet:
RC6802 Serial Chicken
$2200
$2400
$2600
$2800
$2A00
$2C00
$2E00
~RTS
RXD
TXD
VCC
~CTS
GND

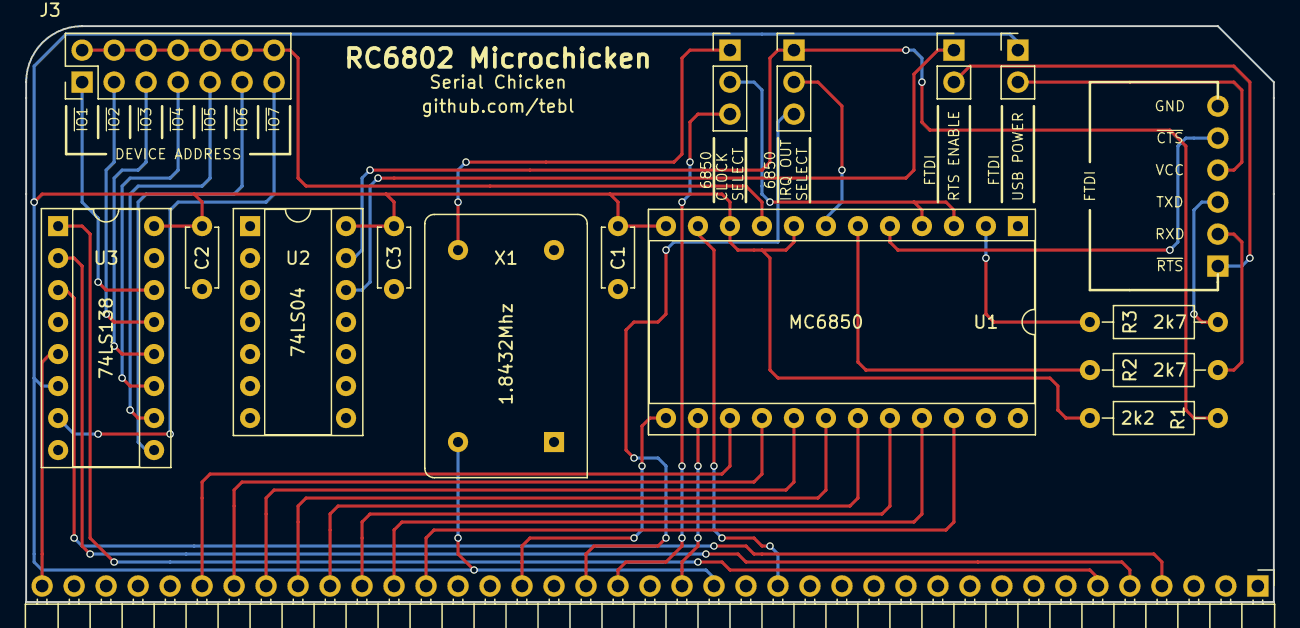
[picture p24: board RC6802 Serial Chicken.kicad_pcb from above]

Board: 2 copper layers, 99.1 x 45.7 mm, 17 parts (1 on the bottom side), 39 nets.

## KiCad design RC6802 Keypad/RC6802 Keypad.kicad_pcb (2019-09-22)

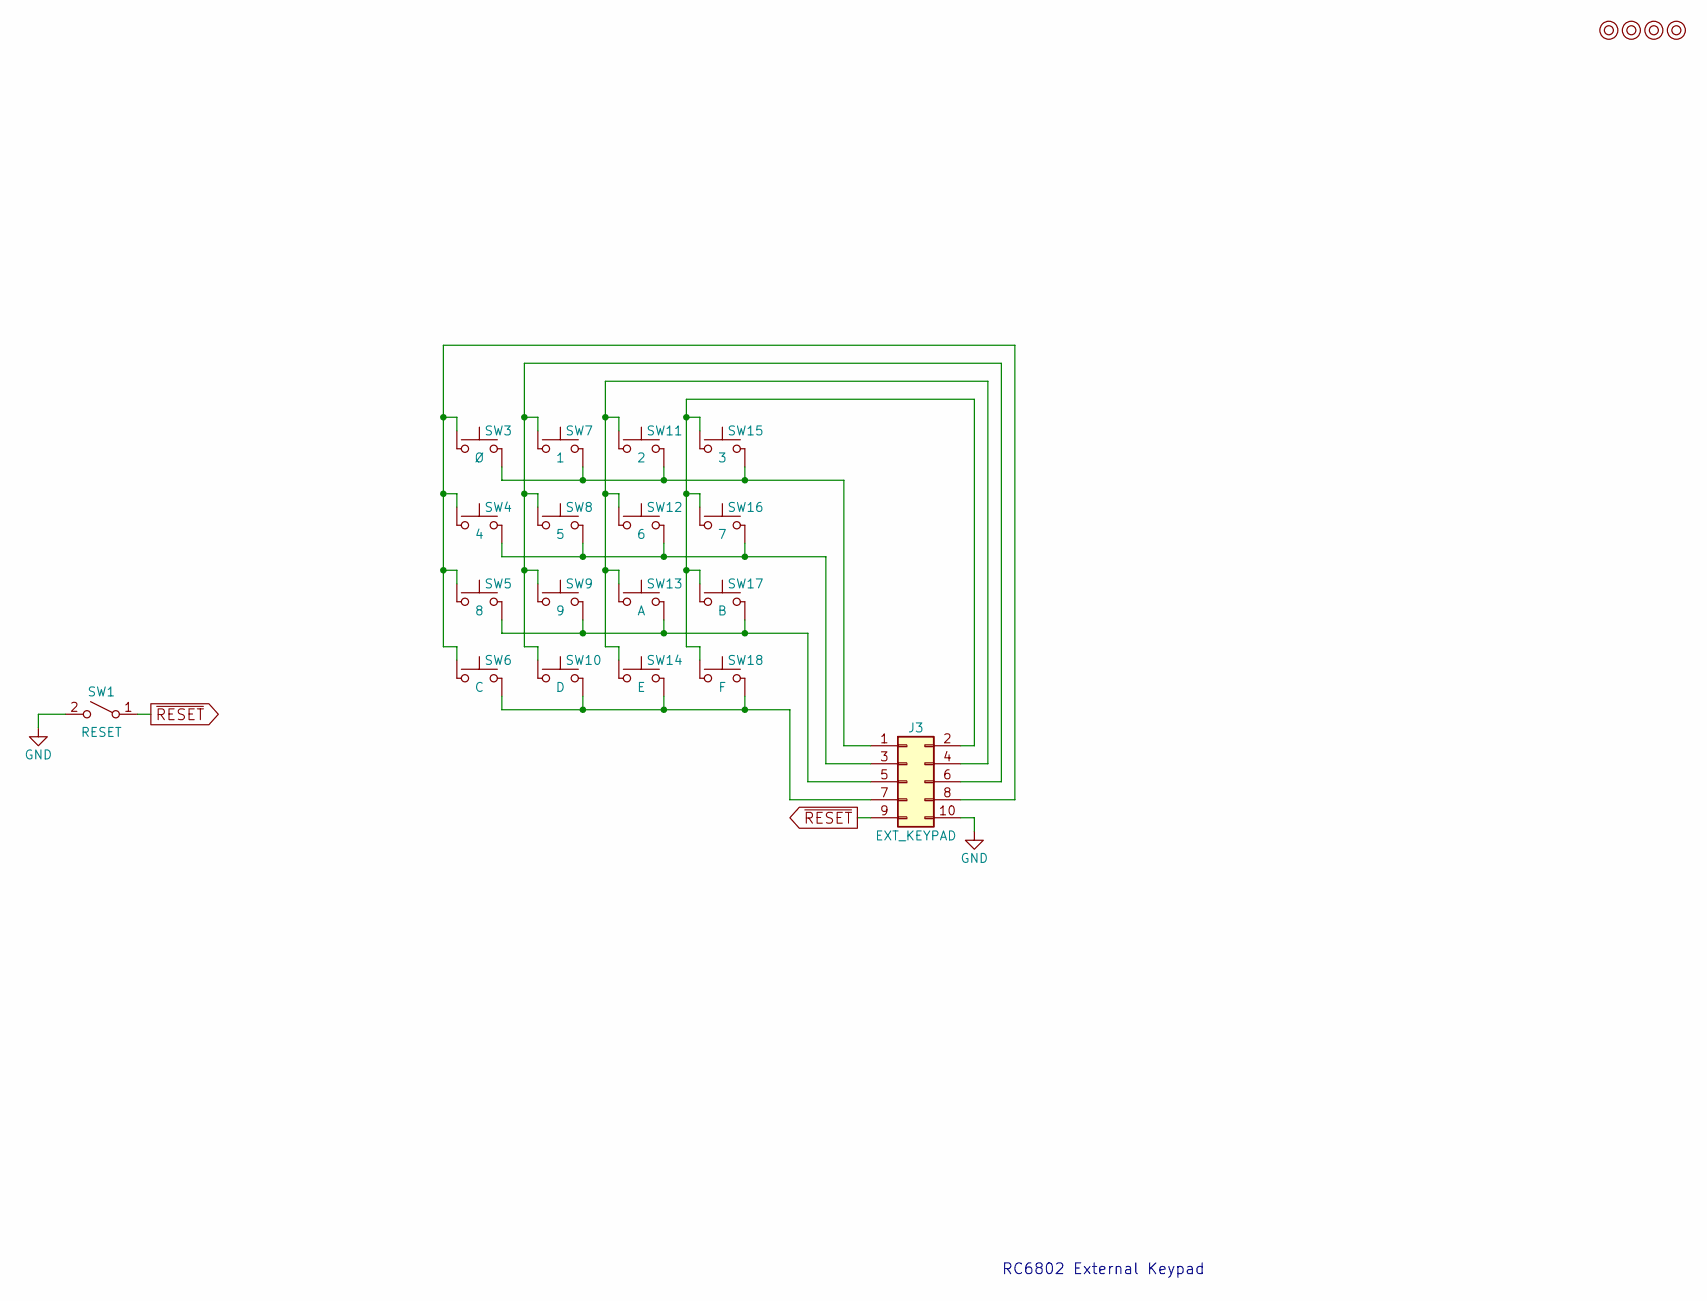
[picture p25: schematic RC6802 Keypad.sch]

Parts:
J3: EXT_KEYPAD; Pin_Header_Straight_2x05_Pitch2.54mm
M1, M2, M3, M4: Mounting; 1pin
SW1: RESET; SW_PUSH_6mm
SW3: Ø; SW_PUSH_6mm
SW4: 4; SW_PUSH_6mm
SW5: 8; SW_PUSH_6mm
SW6: C; SW_PUSH_6mm
SW7: 1; SW_PUSH_6mm
SW8: 5; SW_PUSH_6mm
SW9: 9; SW_PUSH_6mm
SW10: D; SW_PUSH_6mm
SW11: 2; SW_PUSH_6mm
SW12: 6; SW_PUSH_6mm
SW13: A; SW_PUSH_6mm
SW14: E; SW_PUSH_6mm
SW15: 3; SW_PUSH_6mm
SW16: 7; SW_PUSH_6mm
SW17: B; SW_PUSH_6mm
SW18: F; SW_PUSH_6mm

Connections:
GND: J3.10, SW1.2 (B)
unnamed: J3.1, SW3.2, SW7.2, SW11.2, SW15.2
unnamed: J3.2, SW15.1, SW16.1, SW17.1, SW18.1
unnamed: J3.3, SW4.2, SW8.2, SW12.2, SW16.2
unnamed: J3.4, SW11.1, SW12.1, SW13.1, SW14.1
unnamed: J3.5, SW5.2, SW9.2, SW13.2, SW17.2
unnamed: J3.6, SW7.1, SW8.1, SW9.1, SW10.1
unnamed: J3.7, SW6.2, SW10.2, SW14.2, SW18.2
unnamed: J3.8, SW3.1, SW4.1, SW5.1, SW6.1
~RESET: J3.9, SW1.1 (A)

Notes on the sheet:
RC6802 External Keypad

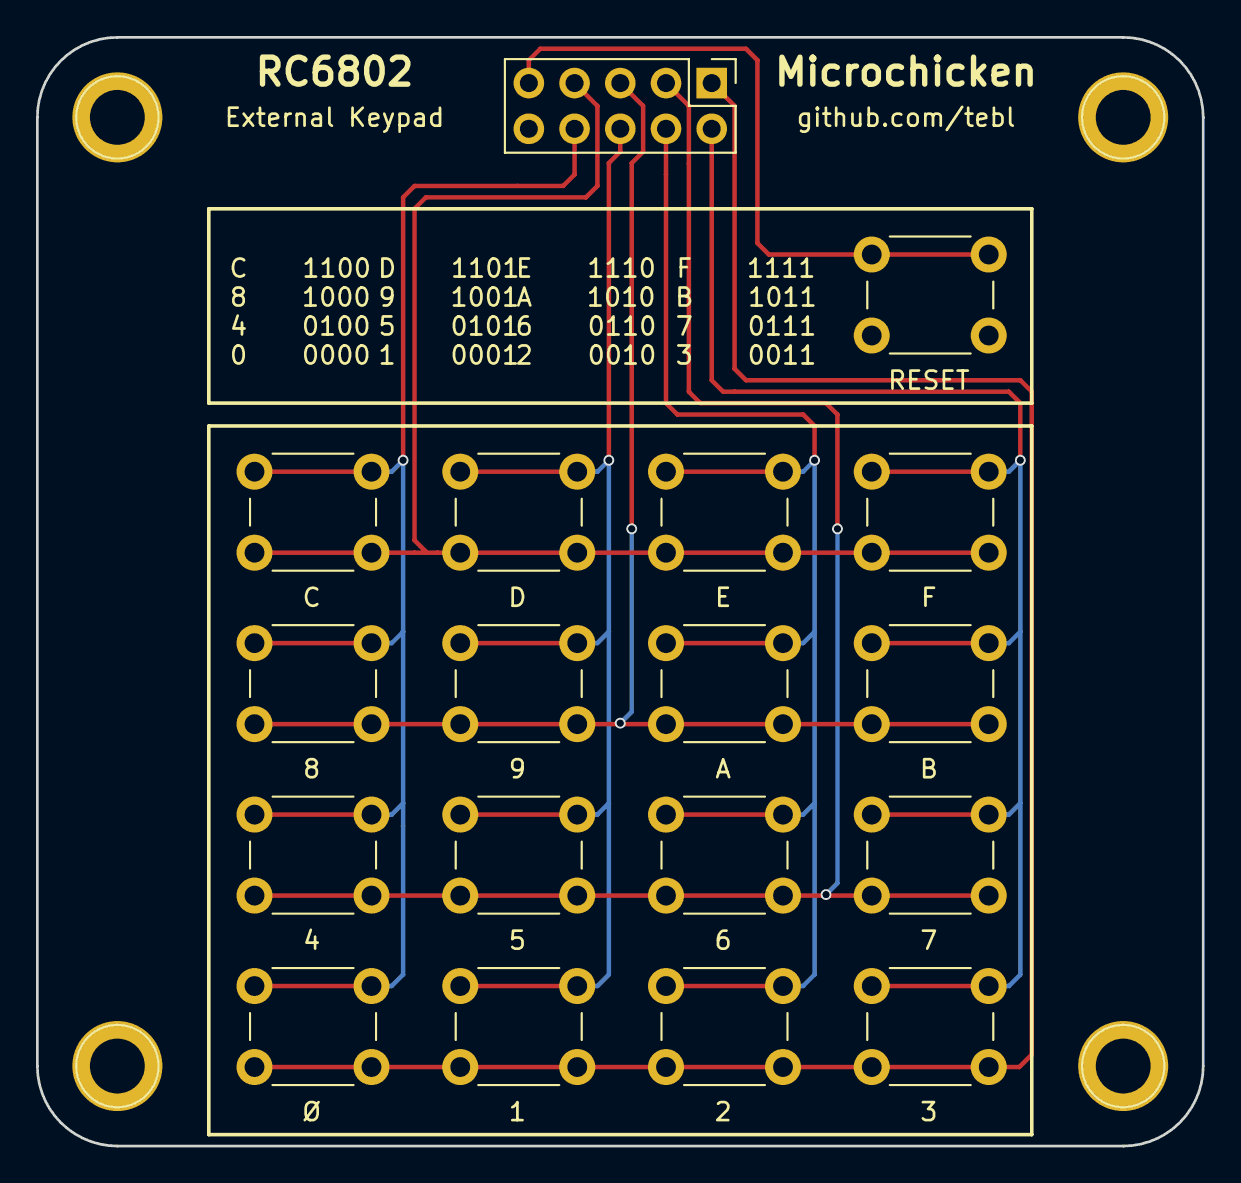
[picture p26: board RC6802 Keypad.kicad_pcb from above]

Board: 2 copper layers, 64.8 x 61.6 mm, 22 parts (0 on the bottom side), 10 nets.

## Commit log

2019-09-18 CPU board schematic draft
    [RC6802 CPU.kicad_pcb, RC6802 CPU.sch]
2019-09-19 CPU board layout done
    [RC6802 CPU.kicad_pcb, RC6802 CPU.sch]
2019-09-19 UI board schematic draft
    [RC6802 CPU.sch, RC6802 UI.kicad_pcb, RC6802 UI.sch]
2019-09-20 Assigned 7segment and tape footprints
    [RC6802 UI.sch]
2019-09-21 UI board layout done
    [RC6802 CPU.kicad_pcb, RC6802 CPU.sch, RC6802 UI.kicad_pcb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]
2019-09-22 Added /VMA to backplane
    [RC6802 CPU.kicad_pcb, RC6802 CPU.sch]
2019-09-22 Added external keypad
    [RC6802 Keypad.kicad_pcb, RC6802 Keypad.sch]
2019-09-22 Added VMA_E signal to backplane
    [RC6802 CPU.kicad_pcb, RC6802 CPU.sch]
2019-09-22 Gerber export
    [RC6802 CPU-B.Cu.gbl, RC6802 CPU-B.Mask.gbs, RC6802 CPU-B.Paste.gbp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]
2019-09-22 Serial chicken schematic
    [RC6802 Serial Chicken.kicad_pcb, RC6802 Serial Chicken.sch]
2019-11-10 Updated software
    [RC6802 CPU-B.Cu.gbl, RC6802 CPU-B.Mask.gbs, RC6802 CPU-B.Paste.gbp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]
2019-11-13 Error in MC6802 footprint
    [RC6802 CPU.kicad_pcb, RC6802 CPU.sch]
2019-11-14 Fixed CPU bugs
    [RC6802 CPU-B.Cu.gbl, RC6802 CPU-B.Mask.gbs, RC6802 CPU-B.Paste.gbp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]
2019-11-14 Updated UI to change footprints
    [RC6802 UI-B.Cu.gbl, RC6802 UI-B.Mask.gbs, RC6802 UI-B.Paste.gbp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]
2019-11-26 Revision B build
    [RC6802 CPU-B.Cu.gbl, RC6802 CPU-B.Mask.gbs, RC6802 CPU-B.Paste.gbp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]
2019-11-26 Added M3 standoff notes to UI
2019-11-27 Fixed silkscreen text
    [RC6802 CPU-B.Cu.gbl, RC6802 CPU-B.Mask.gbs, RC6802 CPU-B.Paste.gbp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]
2019-11-27 UI silkscreen improved
    [RC6802 UI-B.Cu.gbl, RC6802 UI-B.Mask.gbs, RC6802 UI-B.Paste.gbp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]
2019-11-30 Schematic had wrong I/O addresses
    [RC6802 CPU-B.Cu.gbl, RC6802 CPU-B.Mask.gbs, RC6802 CPU-B.Paste.gbp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]
2019-12-01 Beep chaser module
    [RC6802 Beep Chaser-B.Cu.gbl, RC6802 Beep Chaser-B.Mask.gbs, RC6802 Beep Chaser-B.Paste.gbp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]
2019-12-01 Beep-chaser LED examples
2019-12-03 Latch beep chaser outputs on write only
    [RC6802 Beep Chaser-B.Cu.gbl, RC6802 Beep Chaser-B.Mask.gbs, RC6802 Beep Chaser-B.Paste.gbp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]
2019-12-19 Added transistor to drive speaker
    [RC6802 Beep Chaser-B.Cu.gbl, RC6802 Beep Chaser-B.Mask.gbs, RC6802 Beep Chaser-B.Paste.gbp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]
2019-12-20 IC-Tester schematic done
    [RC6802 IC-Tester.kicad_pcb, RC6802 IC-Tester.sch]
2019-12-20 IC-Tester layout
    [RC6802 IC-Tester.kicad_pcb, RC6802 IC-Tester.sch]
2020-01-07 PWR/SBY LEDs swapped
    [RC6802 IC-Tester-B.Cu.gbl, RC6802 IC-Tester-B.Mask.gbs, RC6802 IC-Tester-B.Paste.gbp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]
2020-01-09 IC-Tester original code
    [RC6802 IC-Tester.sch, RC6802 UI.sch]
2020-01-09 Updated with schematic changes from original
